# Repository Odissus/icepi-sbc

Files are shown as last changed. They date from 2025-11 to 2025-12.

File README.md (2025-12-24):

# Icepi SBC

A low-cost single-board computer for the H3 CPU: A cheap yet powerful Linux device that you can take anywhere.



| Interested? [Subscribe to updates!](https://cyao.dev/subscribe.html) | Check out [Icepi Zero](https://github.com/cheyao/icepi-zero) too |
| --- | --- |

If there's a lot of people interested, there's a chance that I'll try to sell this at a relatively low price :P

## Features

- H3 Quad-Core ARM Cortex-A7 @ 1.296GHz CPU
    - Mali400 MP2 OpenGL ES 2.0 GPU
- 512MiB of DDR3 RAM, stable at 696MHz (Upgradable to 1GiB)
- Ethernet PHY, WiFi & Bluetooth
- GPDI video out
- USB connectors:
    - 2x USB-A 
    - 2x USB-C (One OTG port)
    - 1x USB-C 100W PD power port
- 3.5mm audio jack
- uSD card slot
- eMMC 5.1 storage



## System support

The single-board computer is capable of running Linux (debian) and Android ([H3Droid](https://h3droid.com/project)). It can output 4k video via it's GPDI-A connector, output a tty consol via UART, or act as an remote host via ssh.

It's small, compact form factor allows it to be a nice portable computer that you can take anywhere! It supports GPU acceleration and 4k video decoding, letting you view anything in full confort.



## PCB

[Check out the online version here](https://github.com/cheyao/icepi-sbc/tree/main/hardware).

The PCB is only 4 layered, ensuring minimal cost and overhead during production. But for mass production 6 layers is recommended, putting solid ground on In.1 and In.4, then copy the power plane to In.2 and In.3. (Impedance matching might be required depending on stackup)



The current setup uses [JLCPCB's](https://jlcpcb.com/) JLC04161H-3313 stackup, and the BOM is optimized for use there. Using other fabs would require re-tuning the DDR3, USB and GPDI traces.

## Open source

This project is licensed under the [Solderpad](/LICENSE) hardware license, granting the maximum amount of liberty :)

It is also OSHWA certified under the identifier [FR000029](https://certification.oshwa.org/fr000029.html).



## Contact

Any questions? Dm `@Cyao.` on Discord (Send a friend request or join the KiCAD Discord server) or send an email to `cyao _at_ duck.com`!

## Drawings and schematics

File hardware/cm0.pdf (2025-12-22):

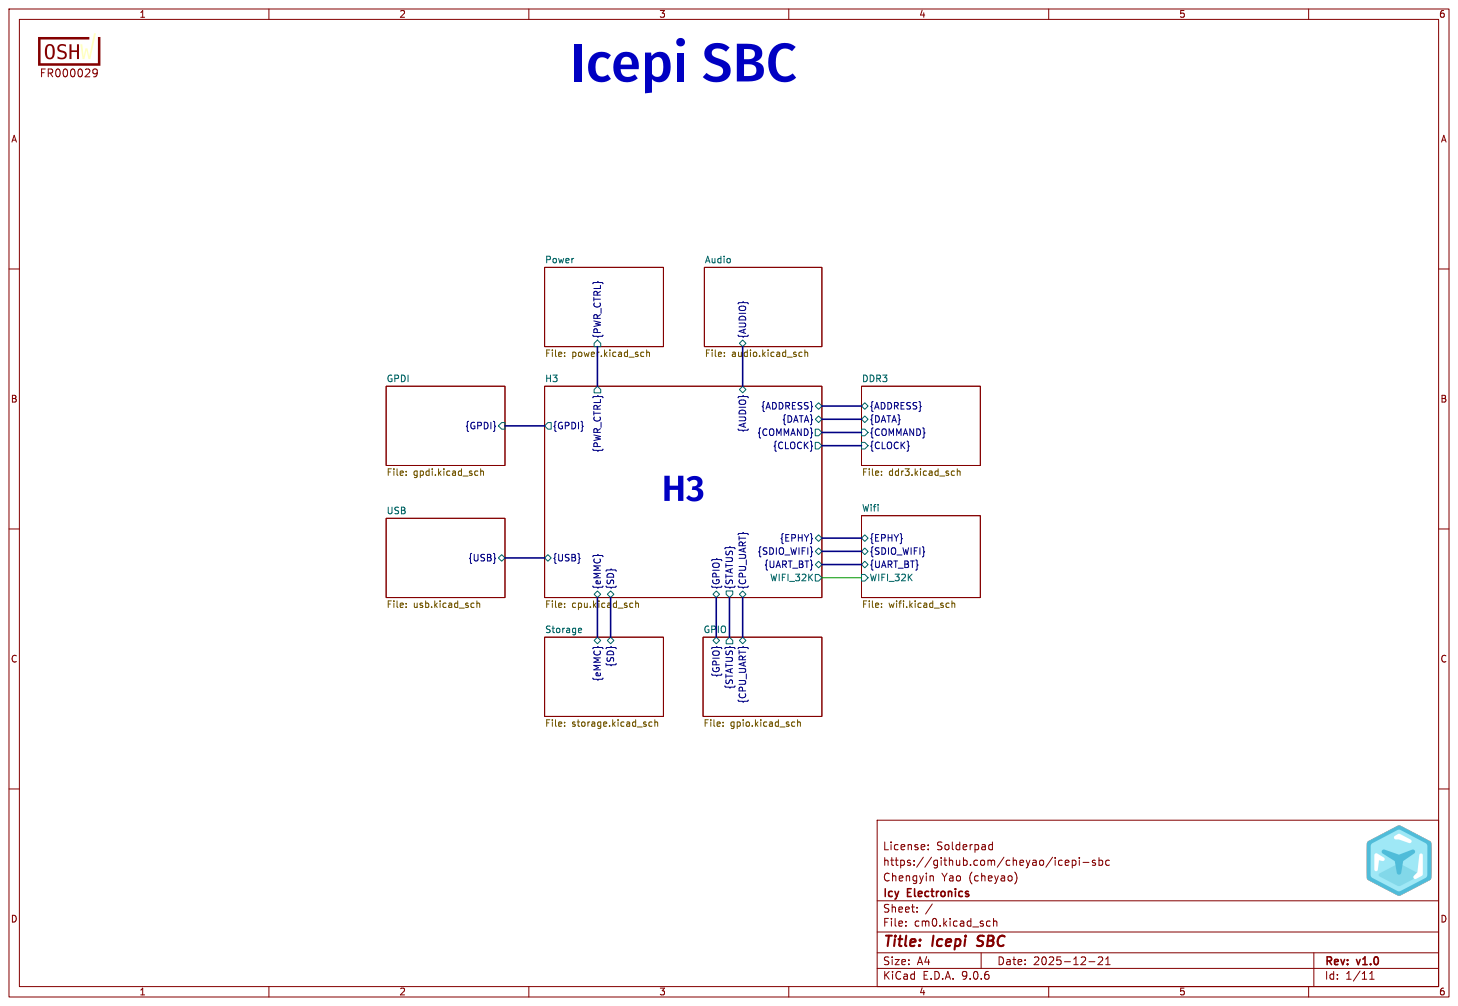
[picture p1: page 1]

File: gpio.kicad_sch {PWR_CTRL} Power File: power.kicad_sch

{EPHY} Wifi File: wifi.kicad_sch {CPU_UART} {STATUS} {GPIO} GPIO

https://github.com/cheyao/icepi-sbc License: Solderpad

File: cm0.kicad_sch Sheet: /
Id: 1/11 Title: Icepi SBC

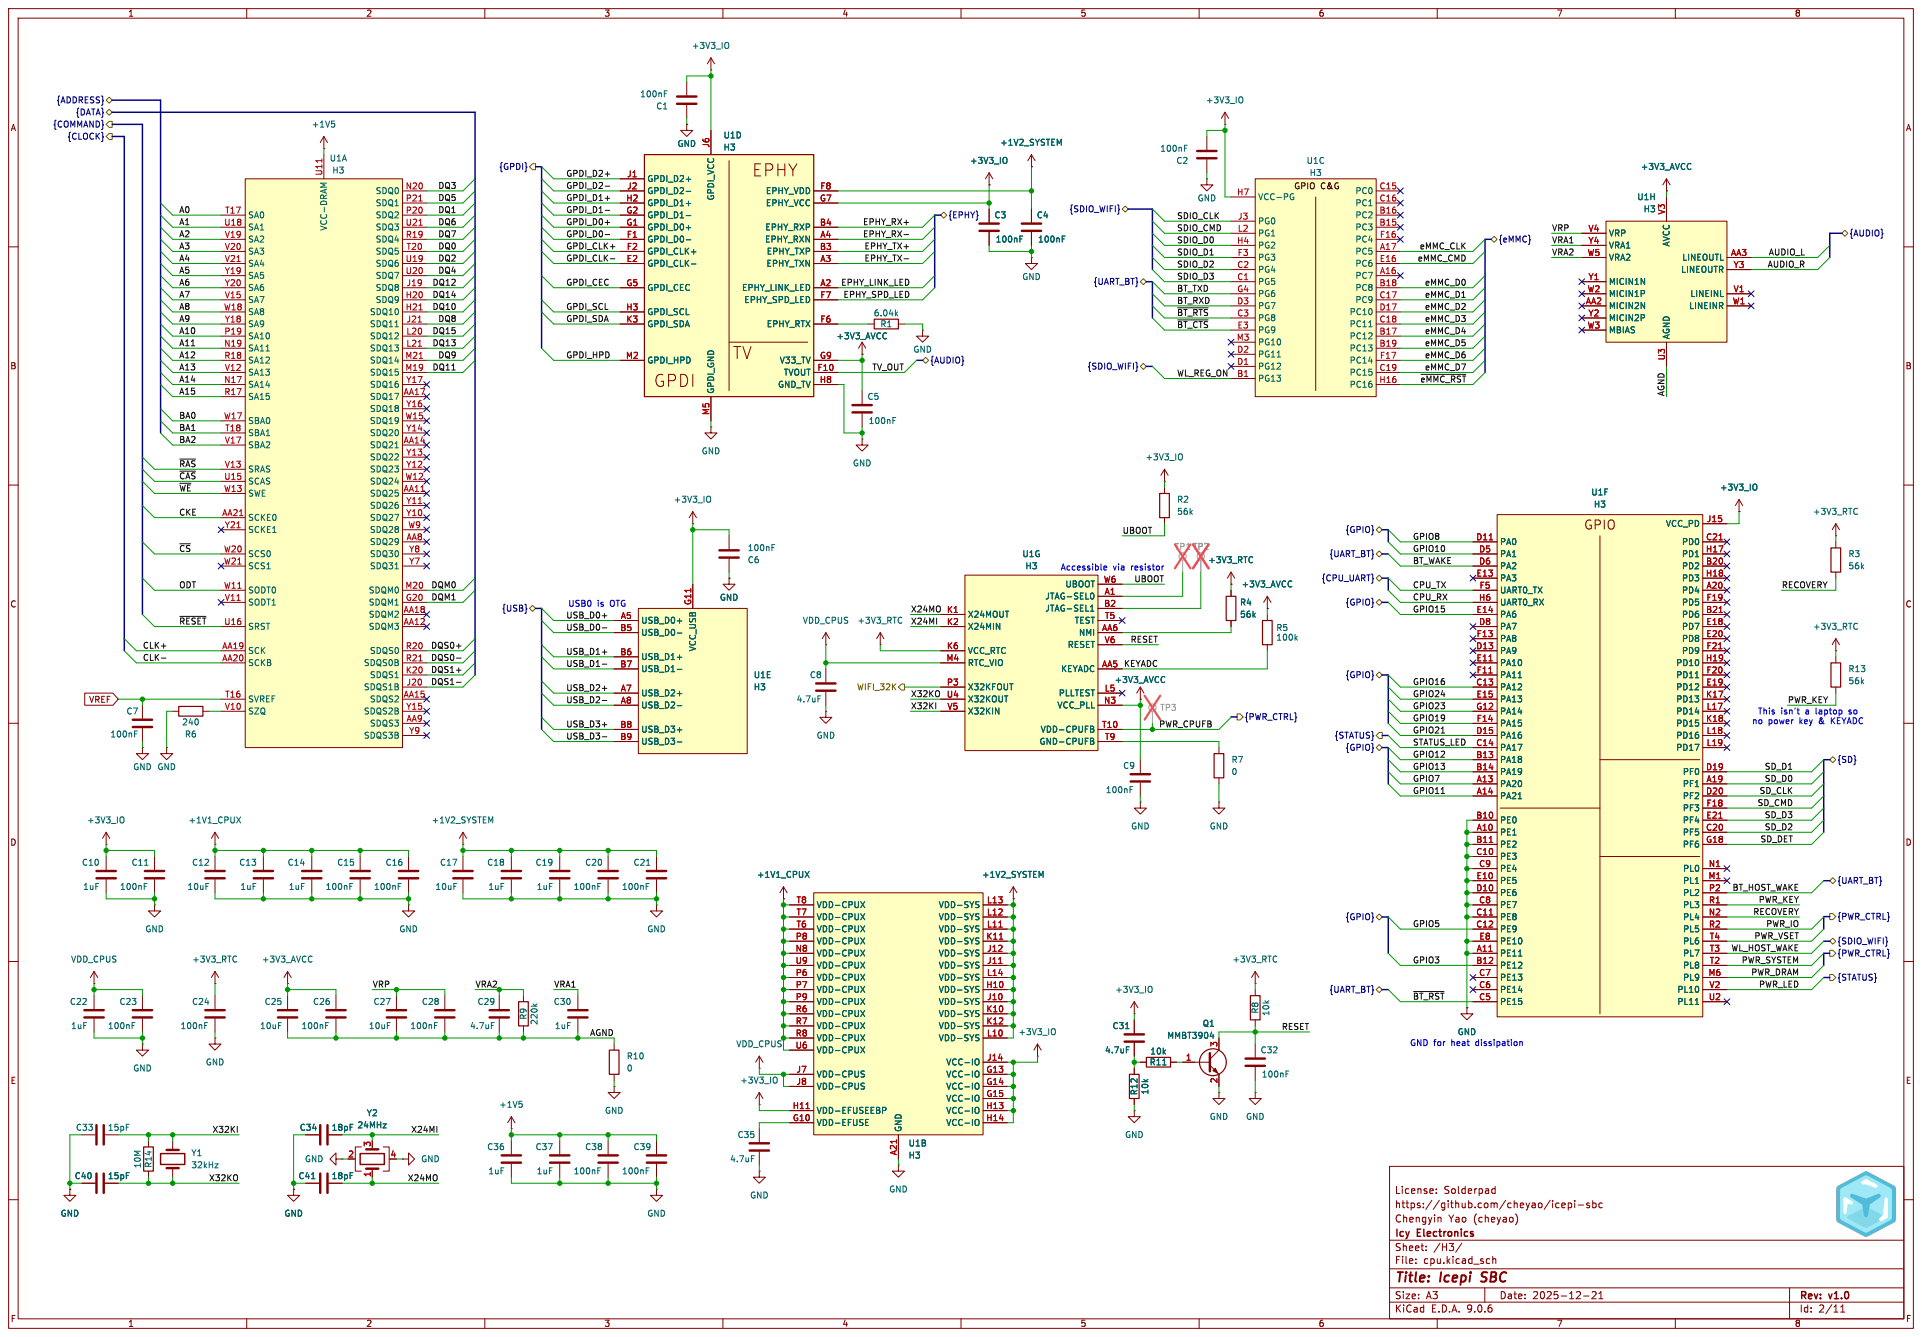
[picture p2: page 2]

3 2 Q1 MMBT3904 +1V2_SYSTEM VCC-DRAM U11 SA0 T17 SA1 U18 SA2 V19 SA3 V20 SA4 V21 SA5 Y19 SA6 Y20 SA7 V15 SA8 W18 SA9 Y18 SA10 P19 SA11 N19 SA12 R18 SA13 V12 SA14 N17 SA15 R17 SBA0 W17 SBA1 T18 SBA2 V17 SRAS V13 SCAS U15 SWE W13 SCKE0 AA21 SCKE1 Y21 SCS0 W20 SCS1 W21 SODT0 W11 SODT1 V11 SRST U16 SCK AA19 SCKB AA20 SVREF T16 SZQ V10

This isn't a laptop so
no power key & KEYADC

https://github.com/cheyao/icepi-sbc License: Solderpad C29

File: cpu.kicad_sch Sheet: /H3/
Id: 2/11 Title: Icepi SBC

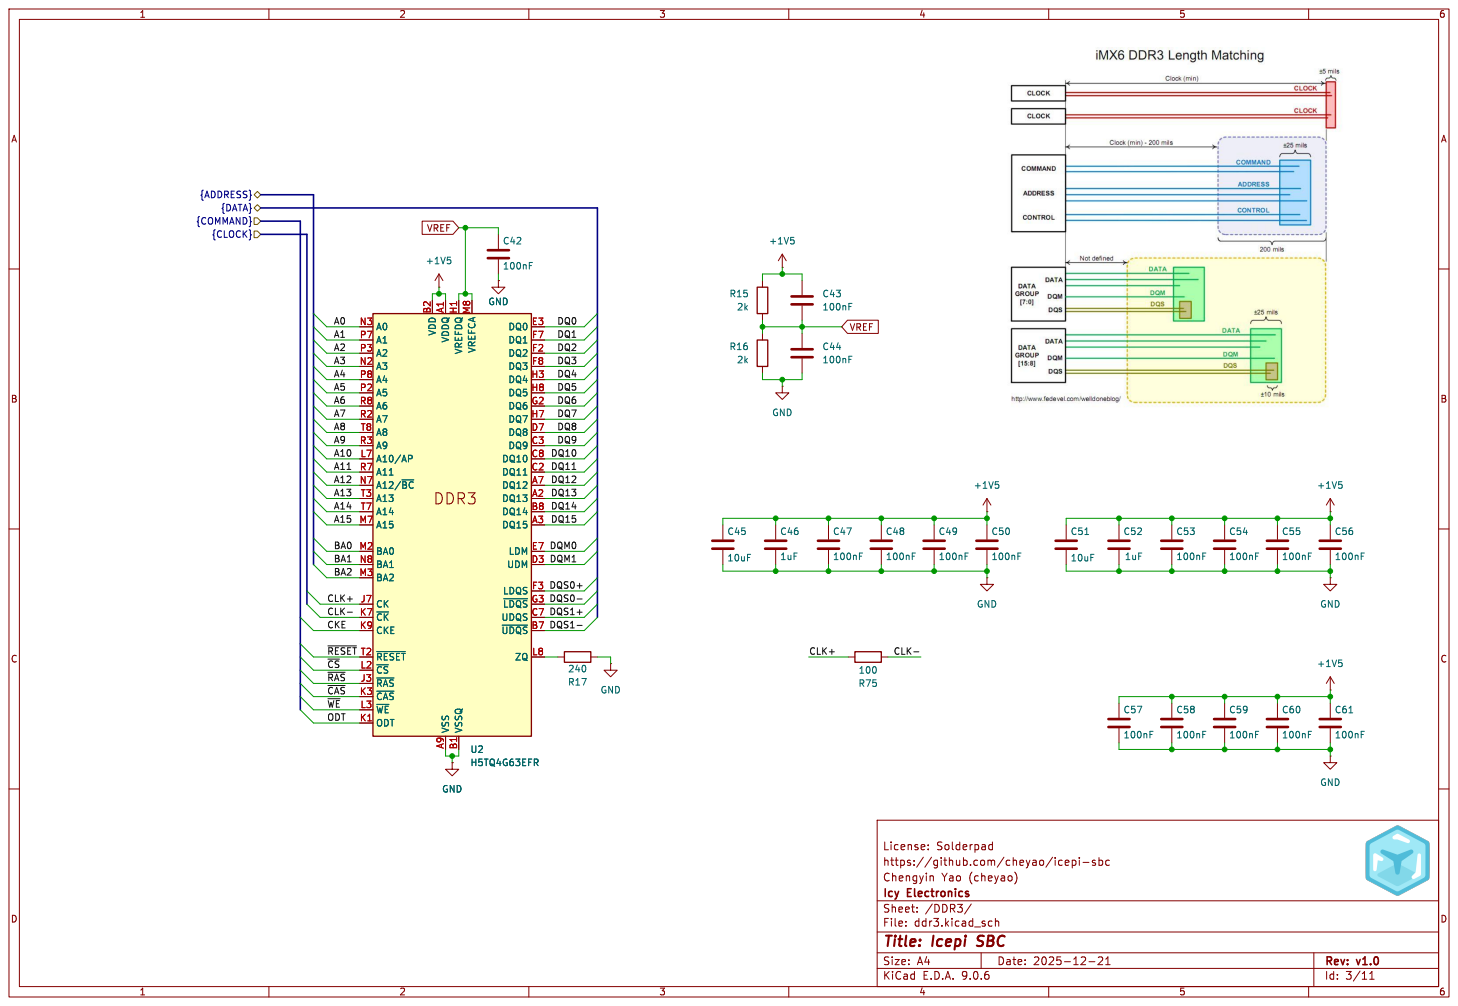
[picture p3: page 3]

https://github.com/cheyao/icepi-sbc License: Solderpad C46

File: ddr3.kicad_sch Sheet: /DDR3/
Id: 3/11 Title: Icepi SBC

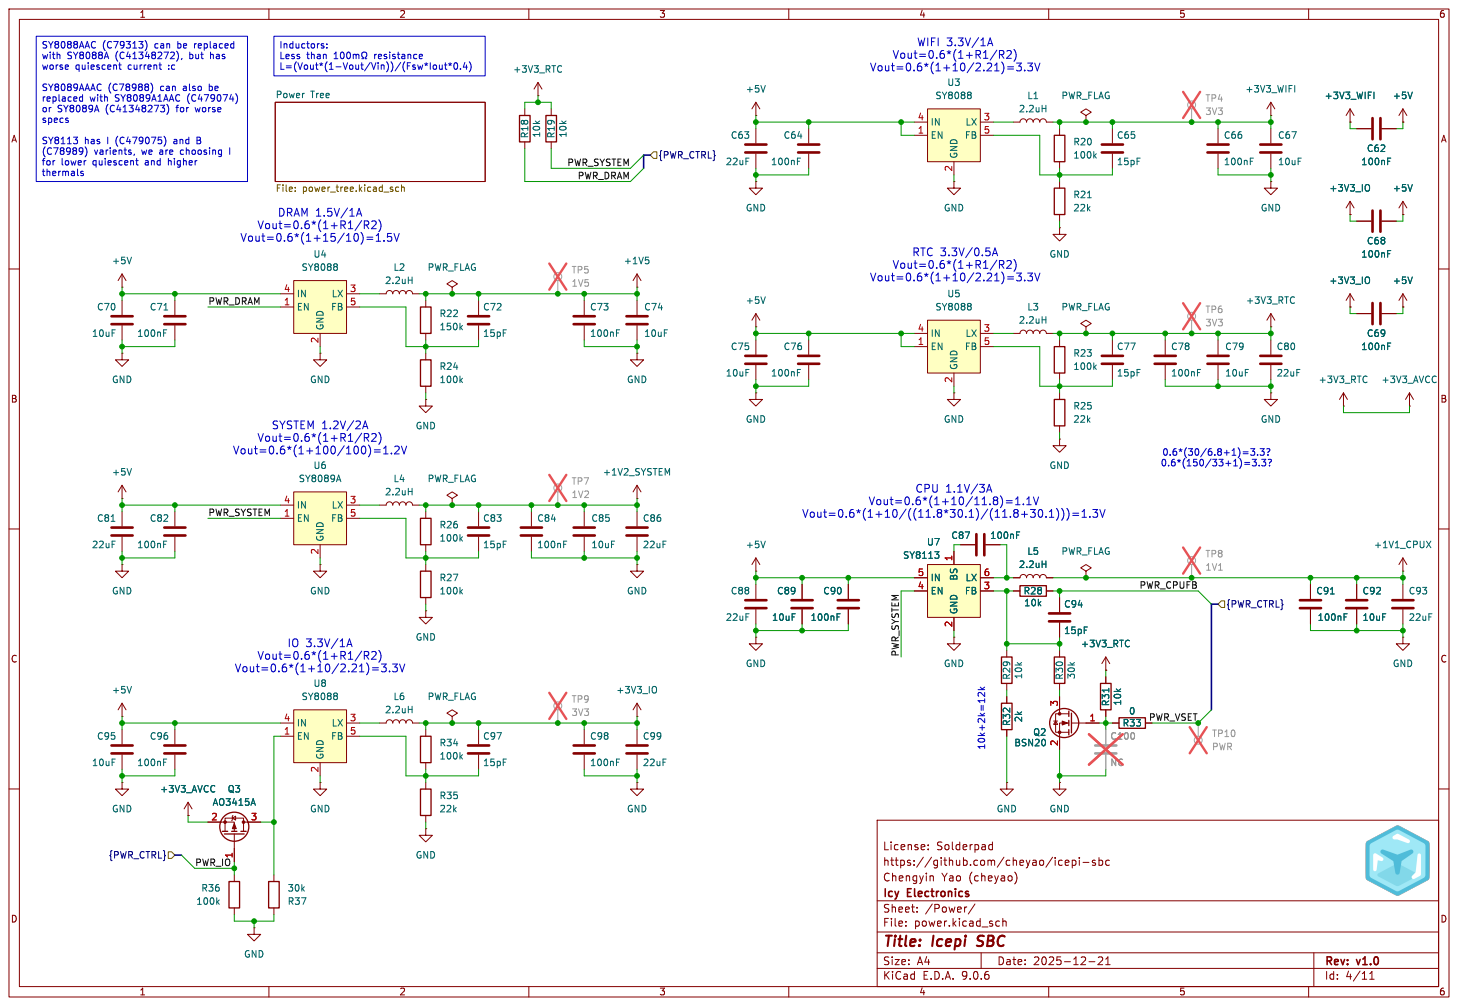
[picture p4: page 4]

Inductors: Less than þÿ100m©resistance

https://github.com/cheyao/icepi-sbc License: Solderpad

File: power.kicad_sch Sheet: /Power/
Id: 4/11 Title: Icepi SBC

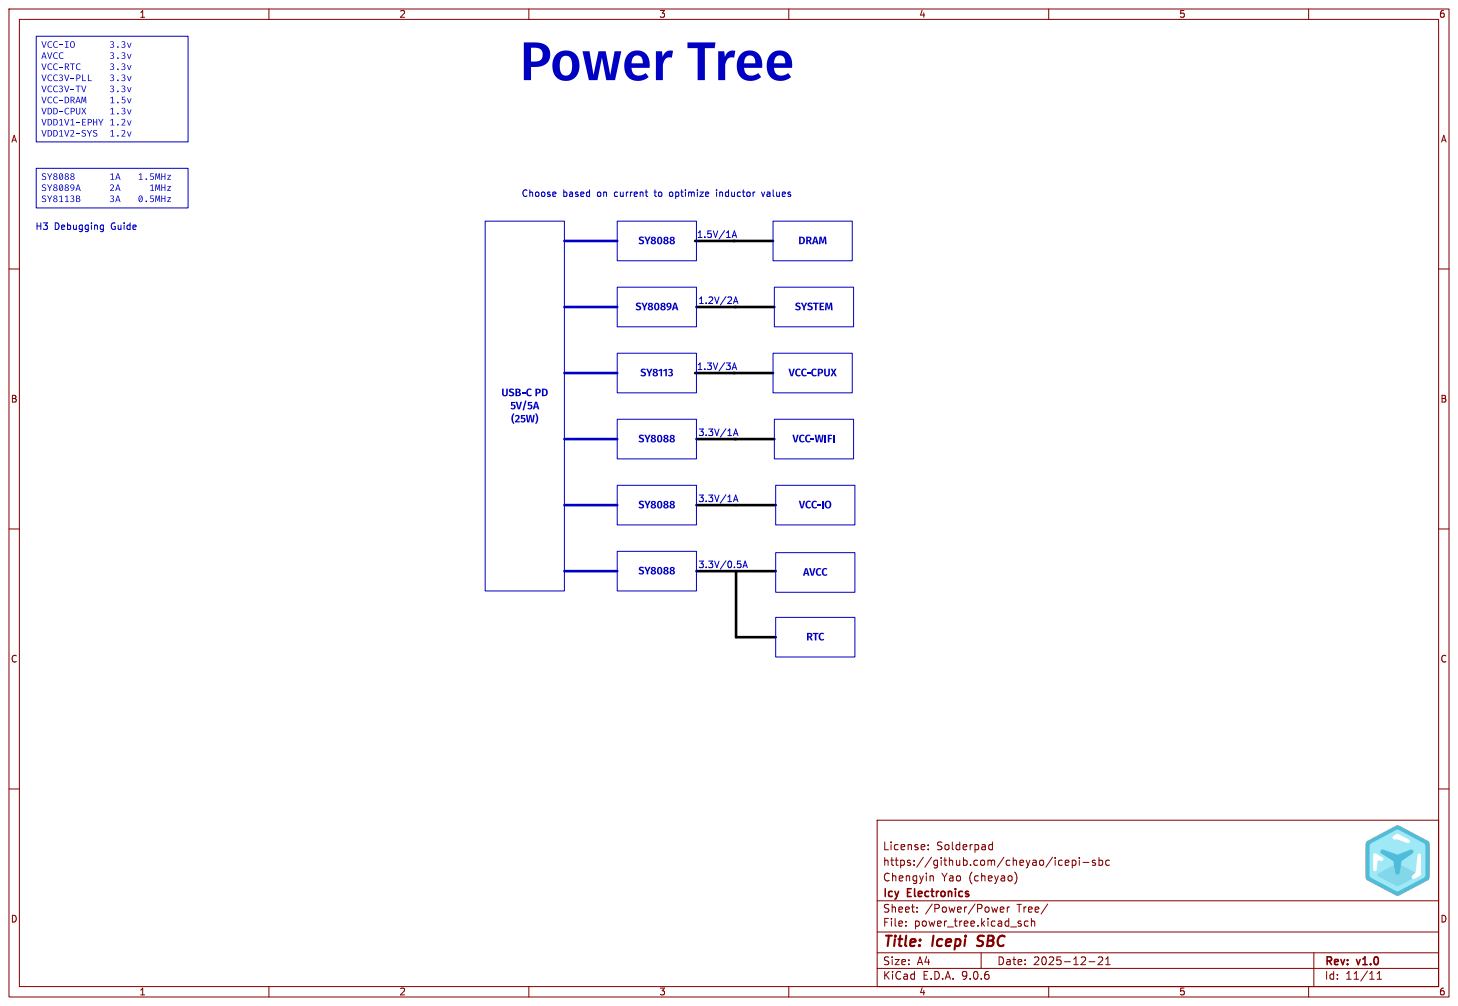
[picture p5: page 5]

https://github.com/cheyao/icepi-sbc License: Solderpad

Id: 11/11 Title: Icepi SBC

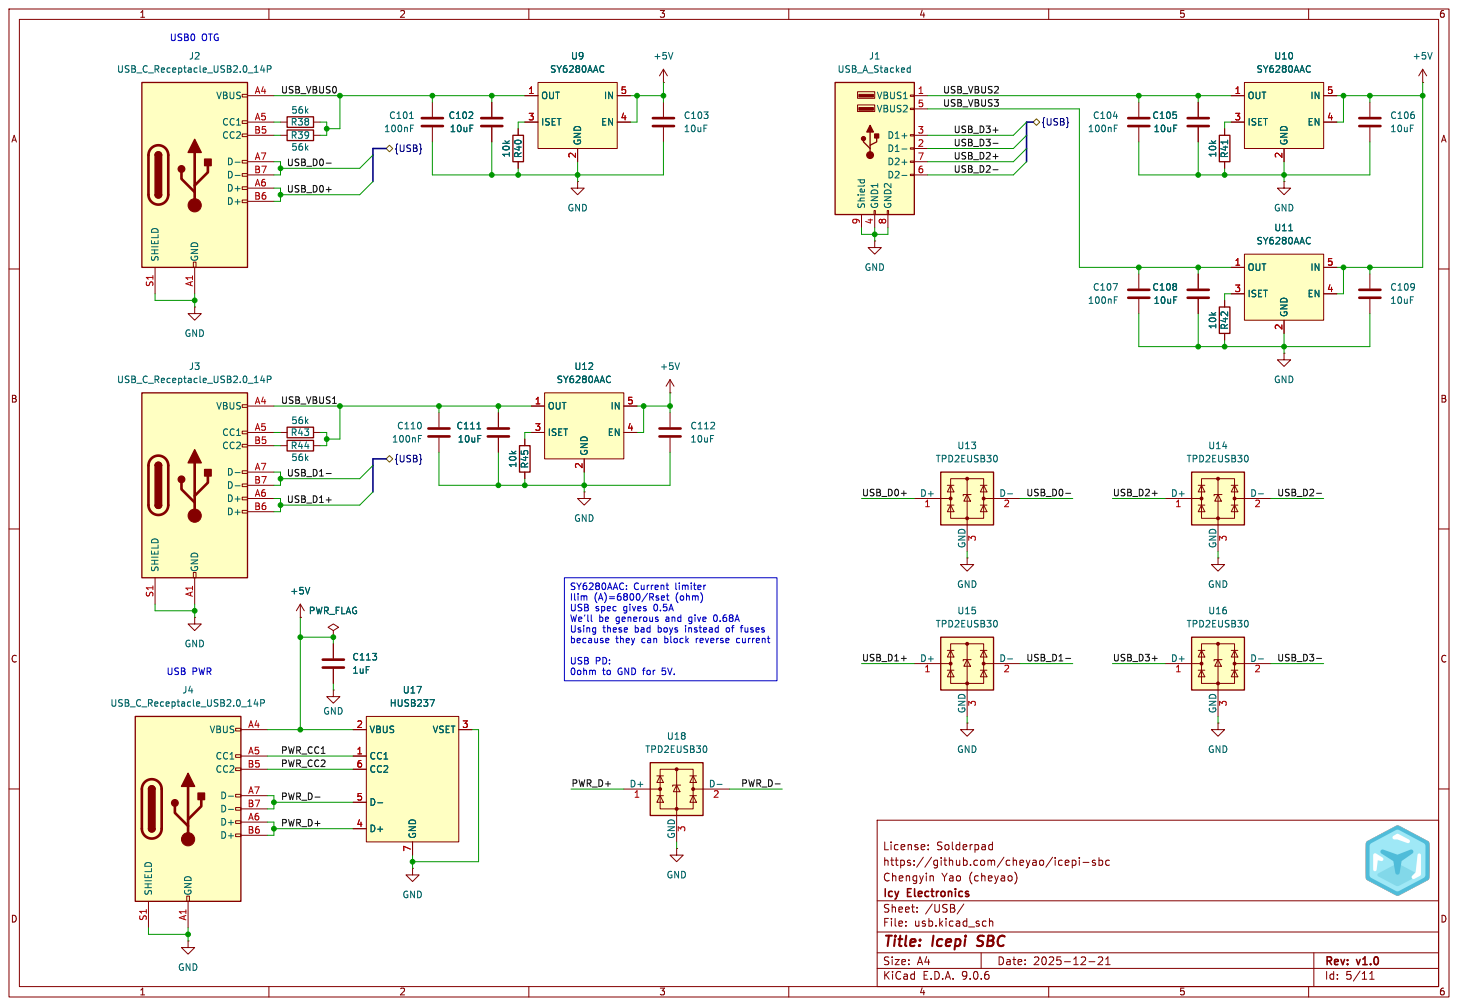
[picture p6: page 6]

https://github.com/cheyao/icepi-sbc License: Solderpad GND

File: usb.kicad_sch Sheet: /USB/
Id: 5/11 Title: Icepi SBC

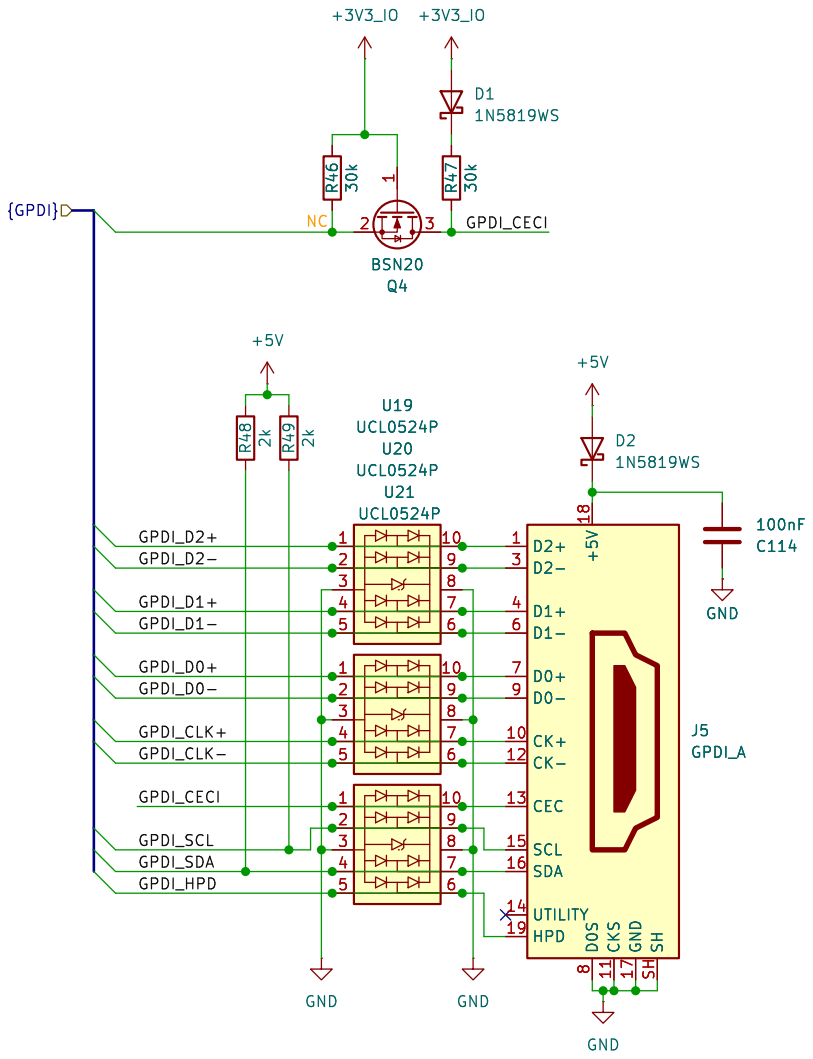
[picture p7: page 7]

https://github.com/cheyao/icepi-sbc License: Solderpad

File: gpdi.kicad_sch Sheet: /GPDI/
Id: 6/11 Title: Icepi SBC

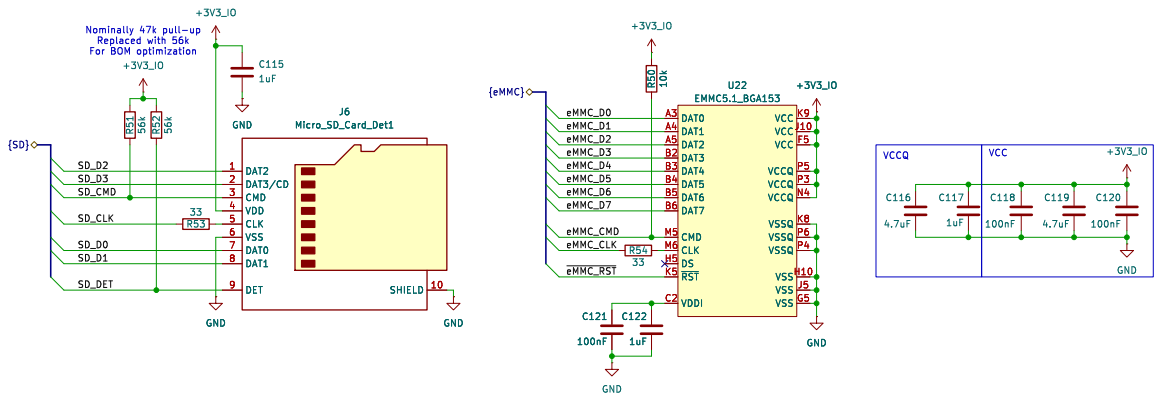
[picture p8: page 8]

https://github.com/cheyao/icepi-sbc License: Solderpad

File: storage.kicad_sch Sheet: /Storage/
Id: 7/11 Title: Icepi SBC

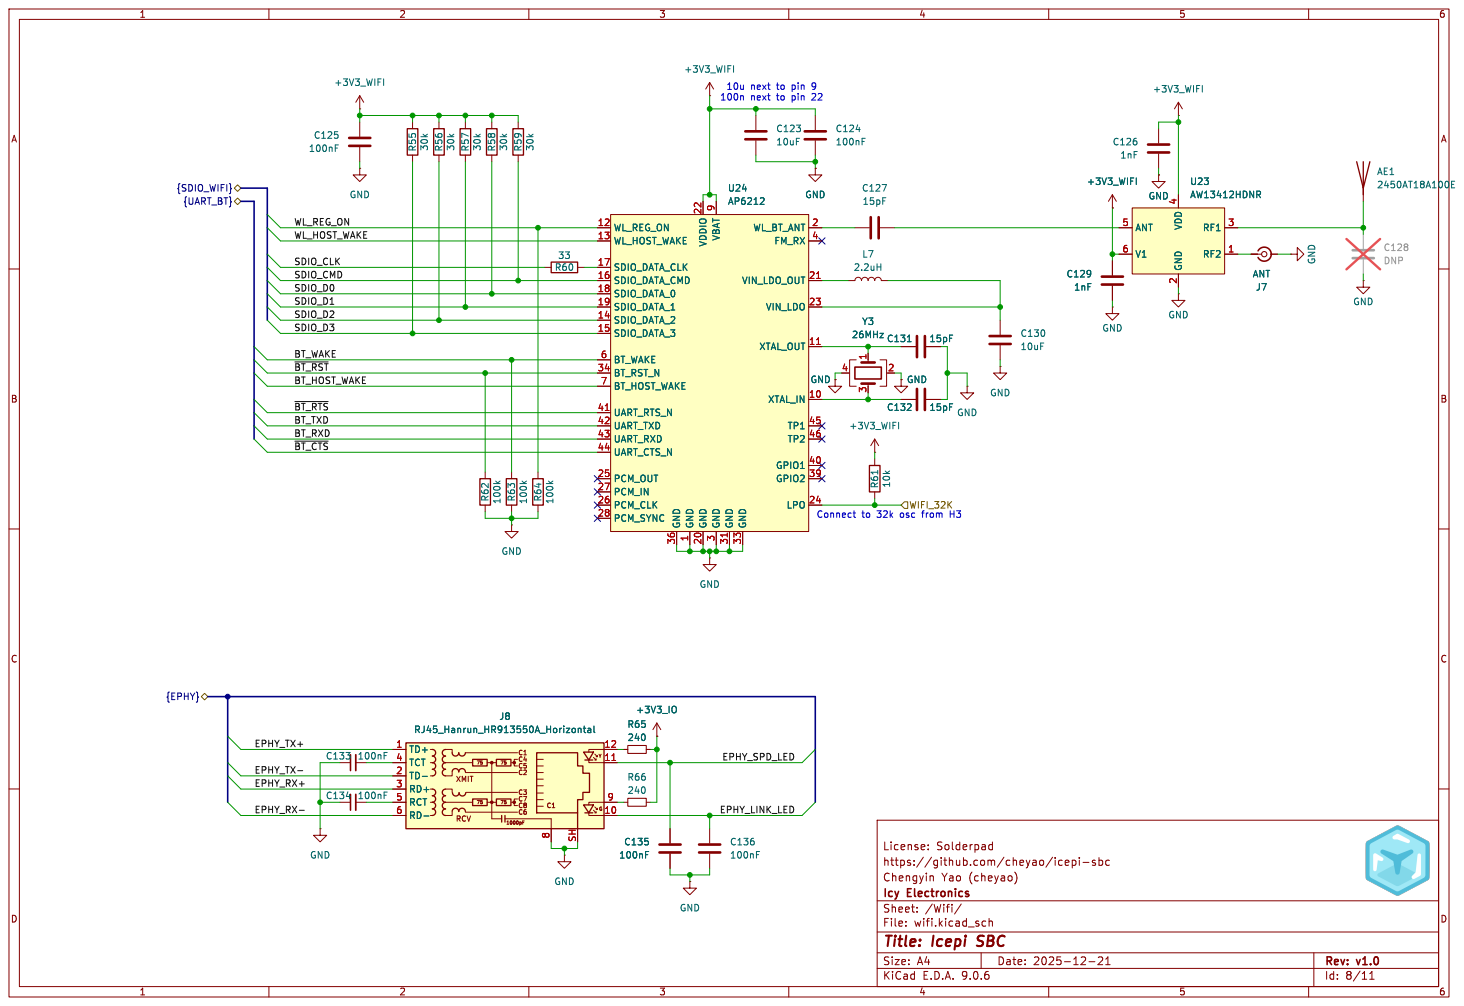
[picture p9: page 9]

10u next to pin 9
100n next to pin 22Connect to 32k osc from H3 GND GND

File: wifi.kicad_sch Sheet: /Wifi/
Id: 8/11 Title: Icepi SBC

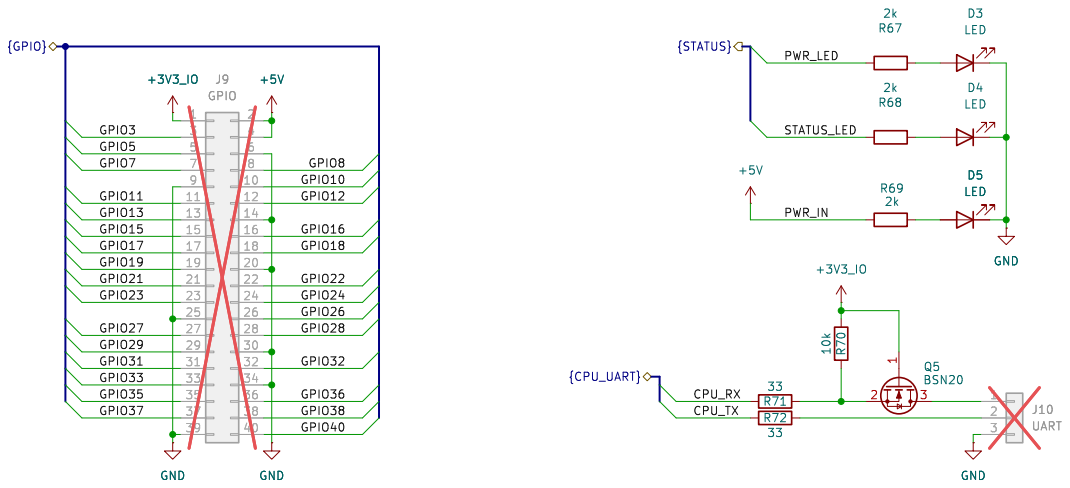
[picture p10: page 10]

File: gpio.kicad_sch Sheet: /GPIO/
Id: 9/11 Title: Icepi SBC

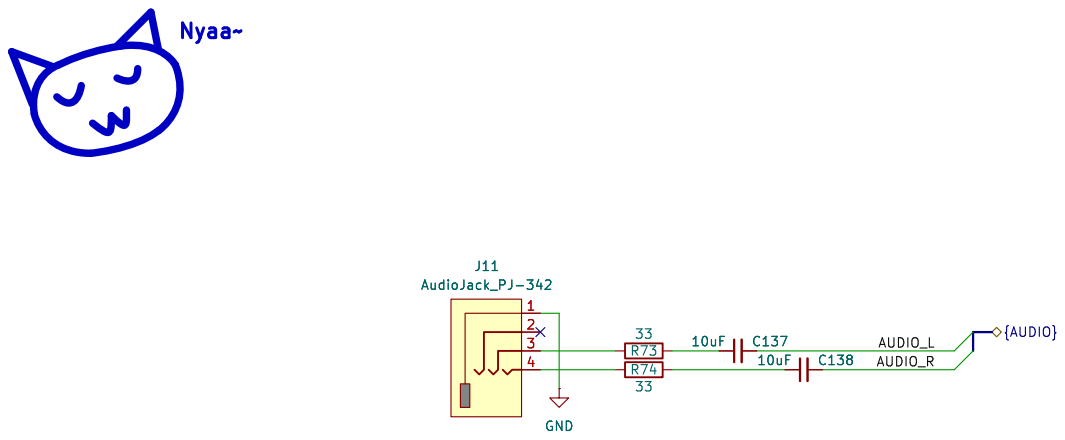
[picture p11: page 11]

https://github.com/cheyao/icepi-sbc License: Solderpad

File: audio.kicad_sch Sheet: /Audio/
Id: 10/11 Title: Icepi SBC

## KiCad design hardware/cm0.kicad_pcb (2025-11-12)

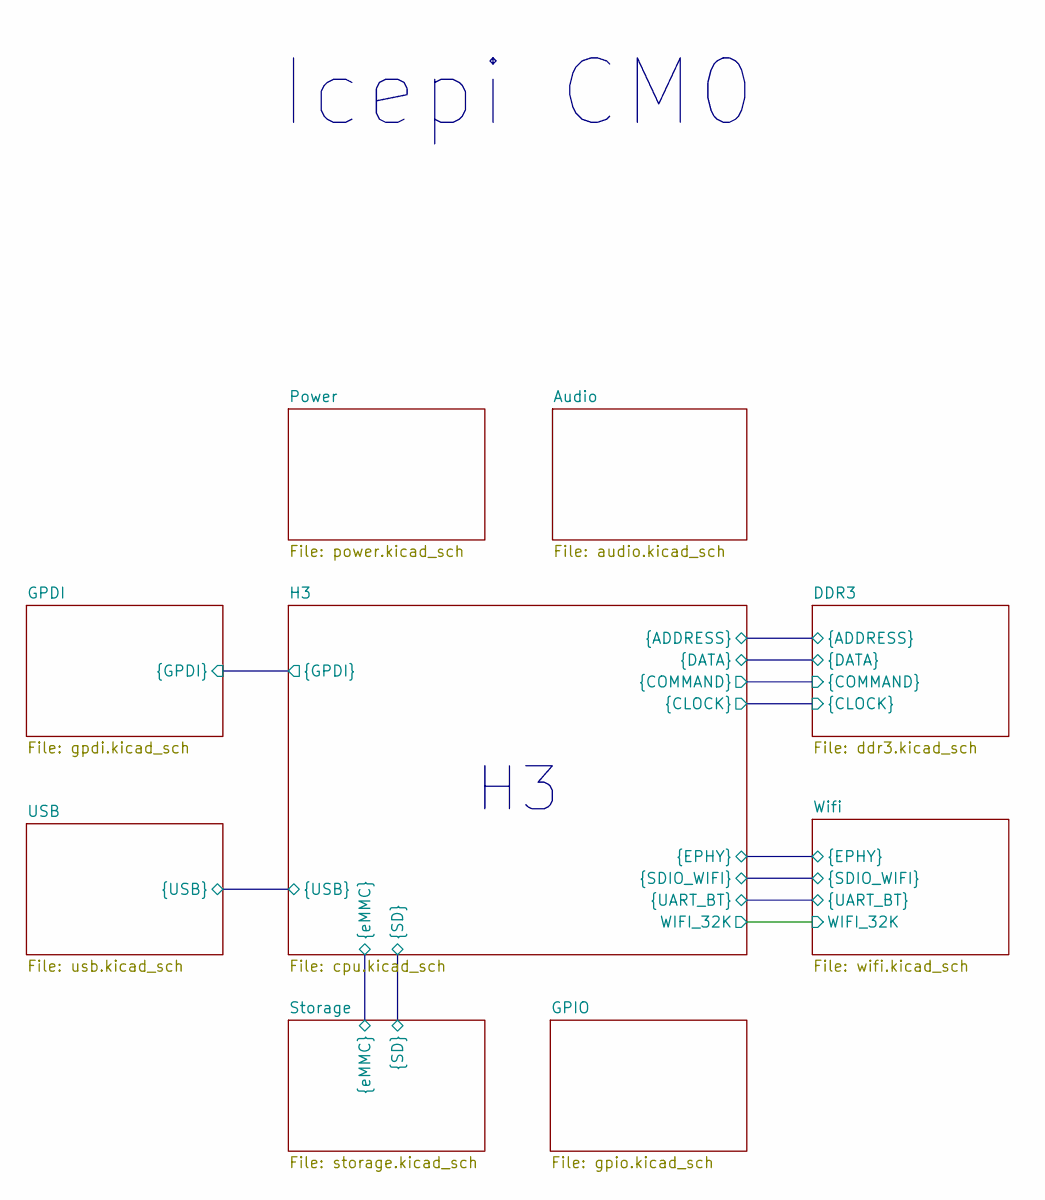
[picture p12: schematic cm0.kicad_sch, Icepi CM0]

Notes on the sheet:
Icepi CM0

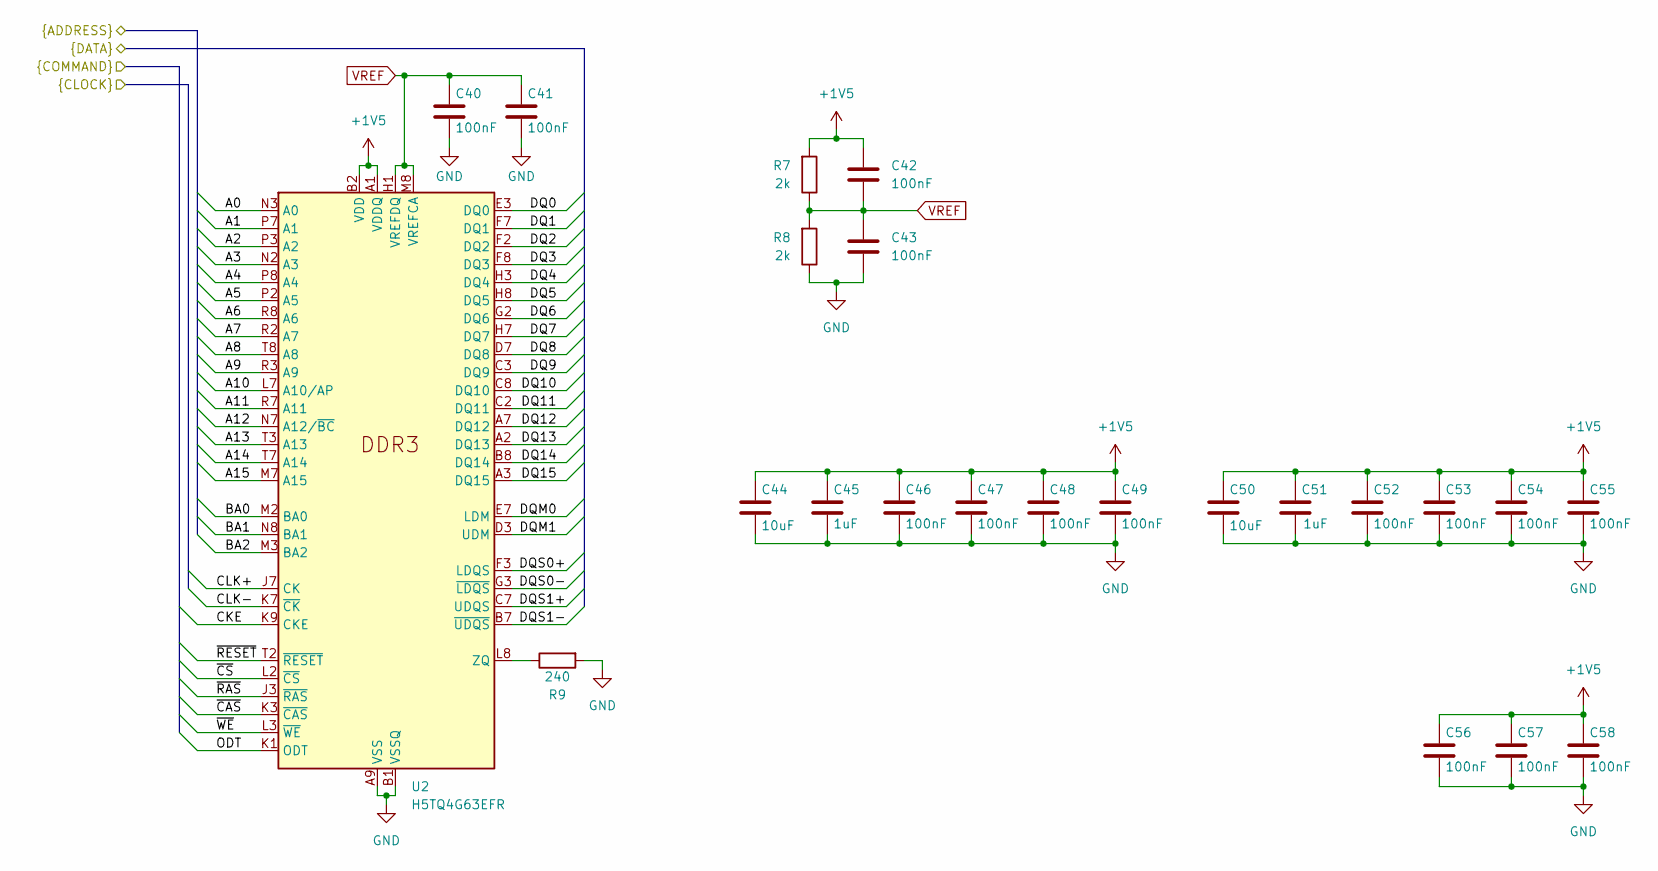
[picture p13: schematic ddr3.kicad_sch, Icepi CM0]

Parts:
C40, C41, C42, C43, C46, C47, C48, C49, C52, C53, C54, C55, C56, C57, C58: 100nF; C_0402_1005Metric; LCSC Part # C1525
C44, C50: 10uF; C_0603_1608Metric; LCSC Part # C19702
C45, C51: 1uF; C_0402_1005Metric; LCSC Part # C52923
R7, R8: 2k; R_0402_1005Metric; LCSC Part # C4109
R9: 240; R_0603_1608Metric; LCSC Part # C23350
U2: H5TQ4G63EFR; FBGA-96_7.5x13mm_Layout9x16_P0.8mm; LCSC Part # C2803259

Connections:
+1V5: C42.1, C44.1, C45.2, C46.1, C47.1, C48.1, C49.1, C50.1, C51.2, C52.1, C53.1, C54.1, C55.1, C56.1, C57.1, C58.1, R7.2, U2.A1 (VDDQ), U2.A8 (VDDQ), U2.B2 (VDD), U2.C1 (VDDQ), U2.C9 (VDDQ), U2.D2 (VDDQ), U2.D9 (VDD), U2.E9 (VDDQ), U2.F1 (VDDQ), U2.G7 (VDD), U2.H2 (VDDQ), U2.H9 (VDDQ), U2.K2 (VDD), U2.K8 (VDD), U2.N1 (VDD), U2.N9 (VDD), U2.R1 (VDD), U2.R9 (VDD); also elsewhere on the board
/DDR3/A0: U2.N3 (A0); also elsewhere on the board
/DDR3/A1: U2.P7 (A1); also elsewhere on the board
/DDR3/A2: U2.P3 (A2); also elsewhere on the board
/DDR3/A3: U2.N2 (A3); also elsewhere on the board
/DDR3/A4: U2.P8 (A4); also elsewhere on the board
/DDR3/A5: U2.P2 (A5); also elsewhere on the board
/DDR3/A6: U2.R8 (A6); also elsewhere on the board
/DDR3/A7: U2.R2 (A7); also elsewhere on the board
/DDR3/A8: U2.T8 (A8); also elsewhere on the board
/DDR3/A9: U2.R3 (A9); also elsewhere on the board
/DDR3/A10: U2.L7 (A10/AP); also elsewhere on the board
/DDR3/A11: U2.R7 (A11); also elsewhere on the board
/DDR3/A12: U2.N7 (A12/~BC); also elsewhere on the board
/DDR3/A13: U2.T3 (A13); also elsewhere on the board
/DDR3/A14: U2.T7 (A14); also elsewhere on the board
/DDR3/A15: U2.M7 (A15); also elsewhere on the board
/DDR3/BA0: U2.M2 (BA0); also elsewhere on the board
/DDR3/BA1: U2.N8 (BA1); also elsewhere on the board
/DDR3/BA2: U2.M3 (BA2); also elsewhere on the board
/DDR3/CKE: U2.K9 (CKE); also elsewhere on the board
/DDR3/CLK+: U2.J7 (CK); also elsewhere on the board
/DDR3/CLK-: U2.K7 (~CK); also elsewhere on the board
/DDR3/DQ0: U2.E3 (DQ0); also elsewhere on the board
/DDR3/DQ1: U2.F7 (DQ1); also elsewhere on the board
/DDR3/DQ2: U2.F2 (DQ2); also elsewhere on the board
/DDR3/DQ3: U2.F8 (DQ3); also elsewhere on the board
/DDR3/DQ4: U2.H3 (DQ4); also elsewhere on the board
/DDR3/DQ5: U2.H8 (DQ5); also elsewhere on the board
/DDR3/DQ6: U2.G2 (DQ6); also elsewhere on the board
/DDR3/DQ7: U2.H7 (DQ7); also elsewhere on the board
/DDR3/DQ8: U2.D7 (DQ8); also elsewhere on the board
/DDR3/DQ9: U2.C3 (DQ9); also elsewhere on the board
/DDR3/DQ10: U2.C8 (DQ10); also elsewhere on the board
/DDR3/DQ11: U2.C2 (DQ11); also elsewhere on the board
/DDR3/DQ12: U2.A7 (DQ12); also elsewhere on the board
/DDR3/DQ13: U2.A2 (DQ13); also elsewhere on the board
/DDR3/DQ14: U2.B8 (DQ14); also elsewhere on the board
/DDR3/DQ15: U2.A3 (DQ15); also elsewhere on the board
/DDR3/DQM0: U2.E7 (LDM); also elsewhere on the board
/DDR3/DQM1: U2.D3 (UDM); also elsewhere on the board
/DDR3/DQS0+: U2.F3 (LDQS); also elsewhere on the board
/DDR3/DQS0-: U2.G3 (~LDQS); also elsewhere on the board
/DDR3/DQS1+: U2.C7 (UDQS); also elsewhere on the board
/DDR3/DQS1-: U2.B7 (~UDQS); also elsewhere on the board
/DDR3/ODT: U2.K1 (ODT); also elsewhere on the board
/DDR3/~CAS: U2.K3 (~CAS); also elsewhere on the board
/DDR3/~CS: U2.L2 (~CS); also elsewhere on the board
/DDR3/~RAS: U2.J3 (~RAS); also elsewhere on the board
/DDR3/~RESET: U2.T2 (~RESET); also elsewhere on the board
/DDR3/~WE: U2.L3 (~WE); also elsewhere on the board
GND: C40.2, C41.2, C43.2, C44.2, C45.1, C46.2, C47.2, C48.2, C49.2, C50.2, C51.1, C52.2, C53.2, C54.2, C55.2, C56.2, C57.2, C58.2, R8.1, R9.2, U2.A9 (VSS), U2.B1 (VSSQ), U2.B3 (VSS), U2.B9 (VSSQ), U2.D1 (VSSQ), U2.D8 (VSSQ), U2.E1 (VSS), U2.E2 (VSSQ), U2.E8 (VSSQ), U2.F9 (VSSQ), U2.G1 (VSSQ), U2.G8 (VSS), U2.G9 (VSSQ), U2.J2 (VSS), U2.J8 (VSS), U2.M1 (VSS), U2.M9 (VSS), U2.P1 (VSS), U2.P9 (VSS), U2.T1 (VSS), U2.T9 (VSS); also elsewhere on the board
unnamed: R9.1, U2.L8 (ZQ)
VREF: C40.1, C41.1, C42.2, C43.1, R7.1, R8.2, U2.H1 (VREFDQ), U2.M8 (VREFCA); also elsewhere on the board

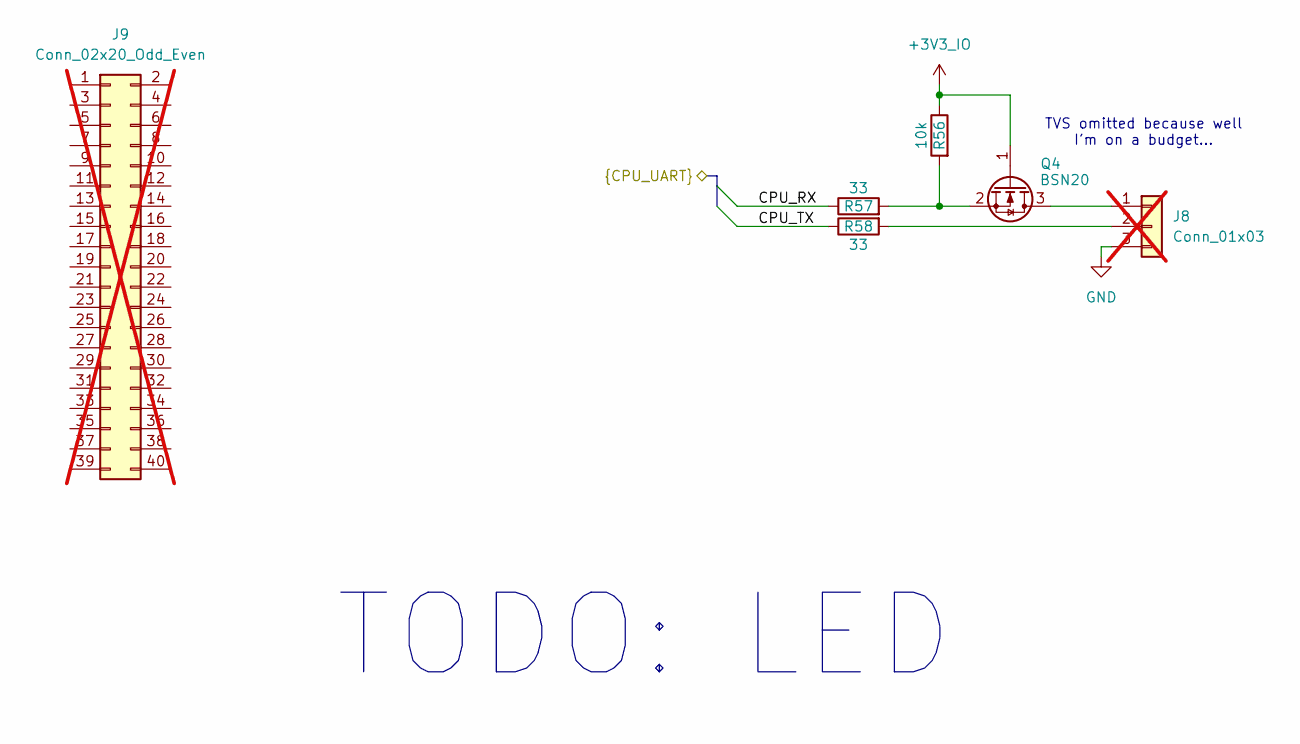
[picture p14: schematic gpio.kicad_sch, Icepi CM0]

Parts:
J8: Conn_01x03; PinHeader_1x03_P2.54mm_Vertical; not fitted
J9: Conn_02x20_Odd_Even; PinHeader_2x20_P2.54mm_Vertical; not fitted
Q4: BSN20; SOT-23; LCSC Part # C116157
R56: 10k; R_0402_1005Metric; LCSC Part # C25744
R57, R58: 33; R_0402_1005Metric; LCSC Part # C25105

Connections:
+3V3_IO: Q4.1 (G), R56.1; also elsewhere on the board
/GPIO/CPU_RX: R57.1; also elsewhere on the board
/GPIO/CPU_TX: R58.1; also elsewhere on the board
GND: J8.3; also elsewhere on the board
unnamed: J8.1, Q4.3 (D)
unnamed: J8.2, R58.2
unnamed: Q4.2 (S), R56.2, R57.2

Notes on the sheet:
TODO: LED
TVS omitted because well I'm on a budget...

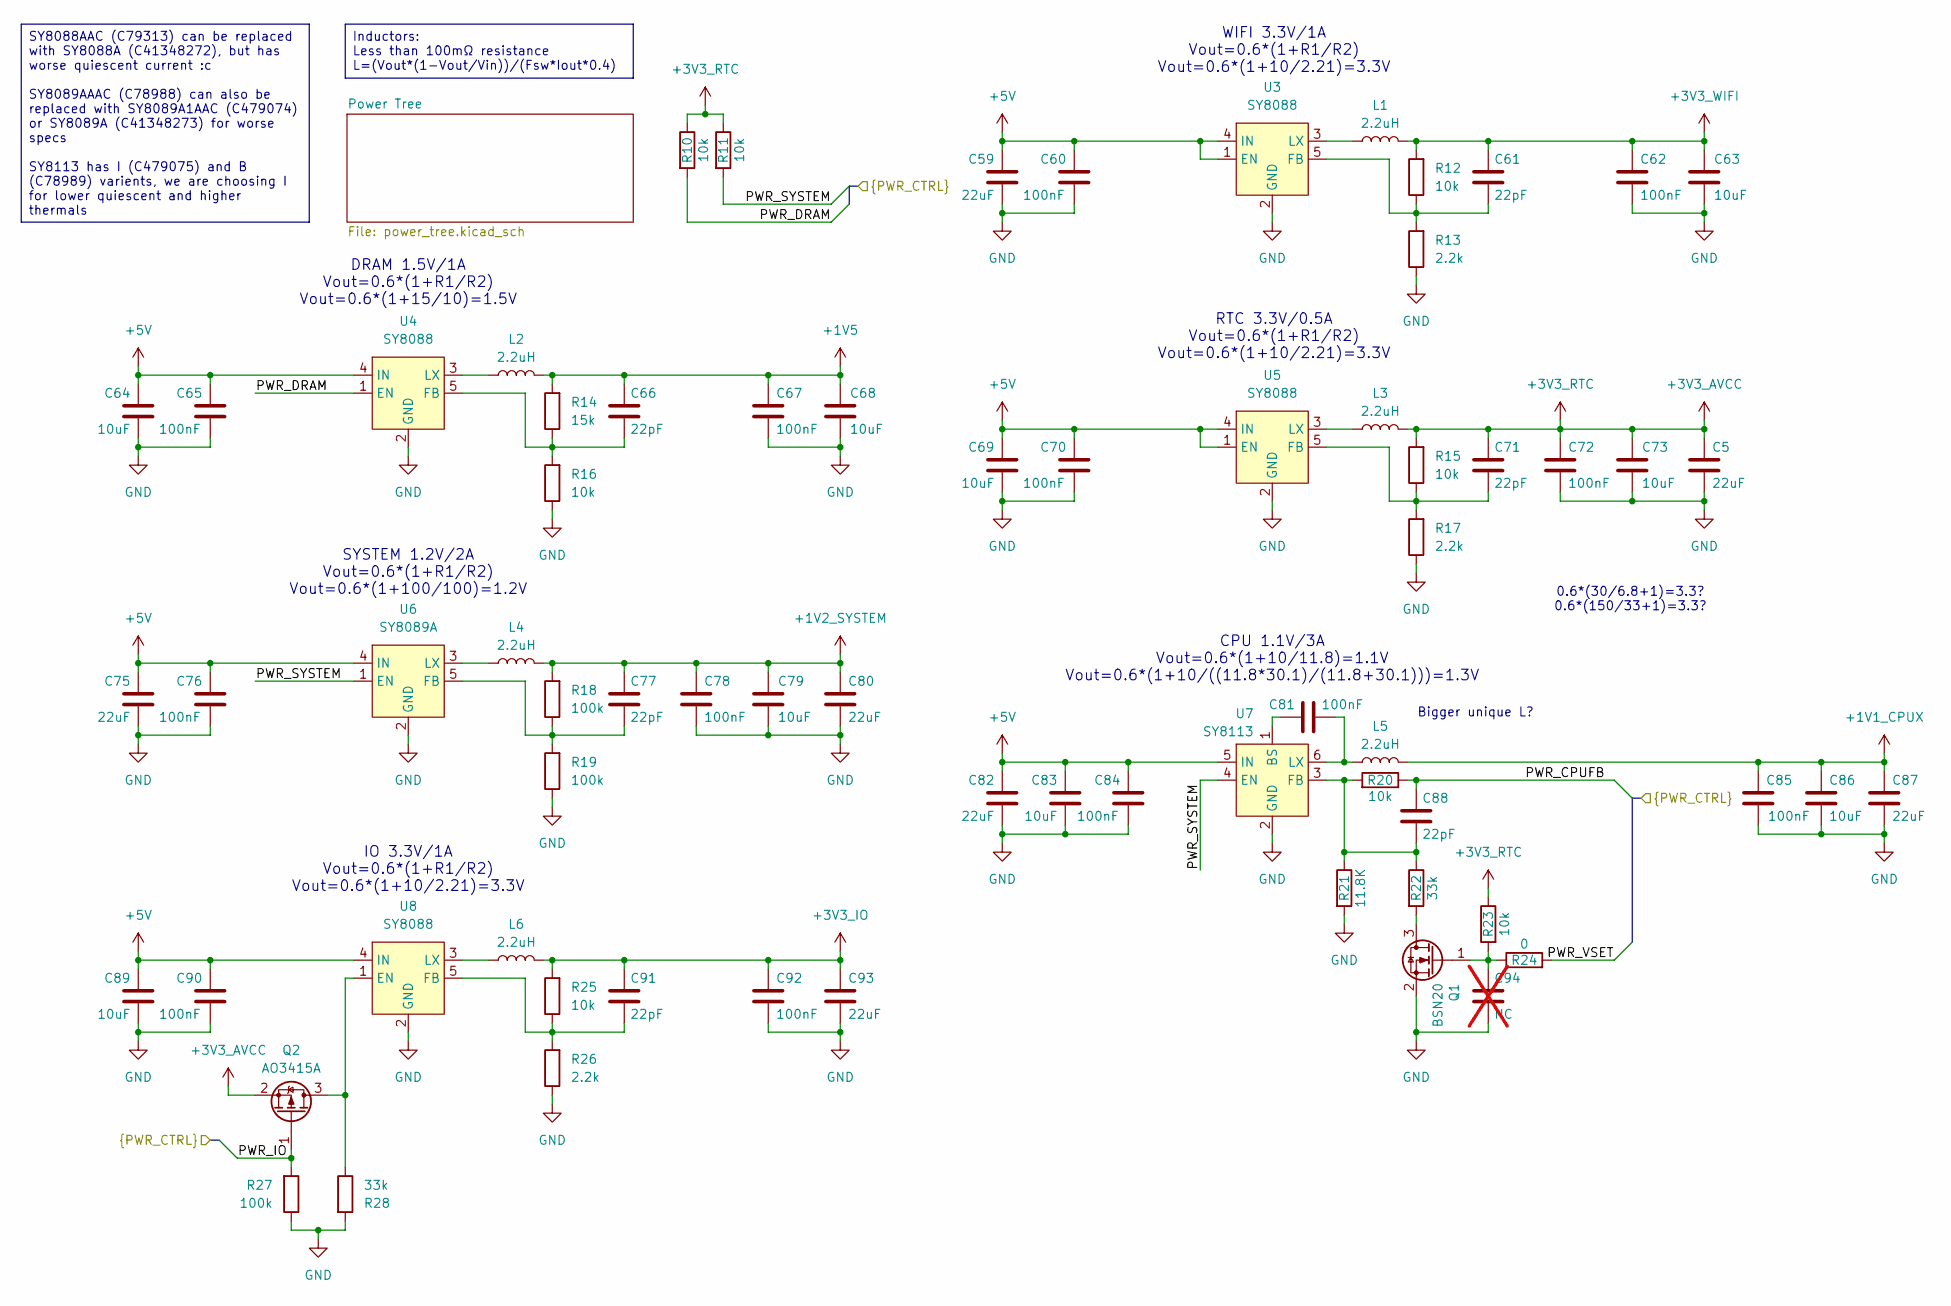
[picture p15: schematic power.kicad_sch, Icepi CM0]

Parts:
C5, C59, C75, C80, C82, C87, C93: 22uF; C_0603_1608Metric; LCSC Part # C59461
C60, C62, C65, C67, C70, C72, C76, C78, C81, C84, C85, C90, C92: 100nF; C_0402_1005Metric; LCSC Part # C1525
C61, C66, C71, C77, C88, C91: 22pF; C_0402_1005Metric; LCSC Part # C1555
C63, C64, C68, C69, C73, C79, C83, C86, C89: 10uF; C_0603_1608Metric; LCSC Part # C19702
C94: NC; C_0402_1005Metric; not fitted
L1, L2, L3, L6: 2.2uH; L_Sunlord_SWPA3015S; LCSC Part # C19734
L4, L5: 2.2uH; L_Sunlord_SWPA4030S; LCSC Part # C135262
Q1: BSN20; SOT-23; LCSC Part # C116157
Q2: AO3415A; SOT-23; LCSC Part # C347479
R10, R11, R12, R15, R16, R20, R23, R25: 10k; R_0402_1005Metric; LCSC Part # C25744
R13, R17, R26: 2.2k; R_0402_1005Metric; LCSC Part # C25879
R14: 15k; R_0402_1005Metric; LCSC Part # C25756
R18, R19, R27: 100k; R_0402_1005Metric; LCSC Part # C25741
R21: 11.8K; R_0402_1005Metric; LCSC Part # C2929934
R22, R28: 33k; R_0402_1005Metric; LCSC Part # C25779
R24: 0; R_0402_1005Metric; LCSC Part # C17168
U3, U4, U5, U8: SY8088; SOT-23-5; LCSC Part # C79313
U6: SY8089A; SOT-23-5; LCSC Part # C78988
U7: SY8113; TSOT-23-6; LCSC Part # C479075

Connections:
+1V1_CPUX: C85.2, C86.1, C87.1, L5.2; also elsewhere on the board
+1V2_SYSTEM: C77.1, C78.2, C79.1, C80.1, L4.2, R18.2; also elsewhere on the board
+1V5: C66.1, C67.2, C68.1, L2.2, R14.2; also elsewhere on the board
+3V3_AVCC: C5.1, C71.1, C72.2, C73.1, L3.2, Q2.2 (S), R10.1, R11.1, R15.2, R23.1; also elsewhere on the board
+3V3_IO: C91.1, C92.2, C93.1, L6.2, R25.2; also elsewhere on the board
+3V3_WIFI: C61.1, C62.2, C63.1, L1.2, R12.2; also elsewhere on the board
+5V: C59.1, C60.2, C64.1, C65.2, C69.1, C70.2, C75.1, C76.2, C82.1, C83.1, C84.2, C89.1, C90.2, U3.1 (EN), U3.4 (IN), U4.4 (IN), U5.1 (EN), U5.4 (IN), U6.4 (IN), U7.5 (IN), U8.4 (IN); also elsewhere on the board
/H3/PWR_CPUFB: C88.1, R20.1; also elsewhere on the board
/H3/PWR_DRAM: R10.2, U4.1 (EN); also elsewhere on the board
/H3/PWR_IO: Q2.1 (G), R27.2; also elsewhere on the board
/H3/PWR_SYSTEM: R11.2, U6.1 (EN), U7.4 (EN); also elsewhere on the board
/H3/PWR_VSET: R24.2; also elsewhere on the board
GND: C5.2, C59.2, C60.1, C62.1, C63.2, C64.2, C65.1, C67.1, C68.2, C69.2, C70.1, C72.1, C73.2, C75.2, C76.1, C78.1, C79.2, C80.2, C82.2, C83.2, C84.1, C85.1, C86.2, C87.2, C89.2, C90.1, C92.1, C93.2, C94.2, Q1.2 (S), R13.1, R16.1, R17.1, R19.1, R21.2, R26.1, R27.1, R28.2, U3.2 (GND), U4.2 (GND), U5.2 (GND), U6.2 (GND), U7.2 (GND), U8.2 (GND); also elsewhere on the board
unnamed: Q1.3 (D), R22.2
unnamed: C94.1, Q1.1 (G), R23.2, R24.1
unnamed: Q2.3 (D), R28.1, U8.1 (EN)
unnamed: C61.2, R12.1, R13.2, U3.5 (FB)
unnamed: L1.1, U3.3 (LX)
unnamed: C66.2, R14.1, R16.2, U4.5 (FB)
unnamed: L2.1, U4.3 (LX)
unnamed: C71.2, R15.1, R17.2, U5.5 (FB)
unnamed: L3.1, U5.3 (LX)
unnamed: C77.2, R18.1, R19.2, U6.5 (FB)
unnamed: L4.1, U6.3 (LX)
unnamed: C81.2, U7.1 (BS)
unnamed: C88.2, R20.2, R21.1, R22.1, U7.3 (FB)
unnamed: C81.1, L5.1, U7.6 (LX)
unnamed: C91.2, R25.1, R26.2, U8.5 (FB)
unnamed: L6.1, U8.3 (LX)

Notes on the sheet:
SYSTEM 1.2V/2A Vout=0.6*(1+R1/R2) Vout=0.6*(1+100/100)=1.2V
WIFI 3.3V/1A Vout=0.6*(1+R1/R2) Vout=0.6*(1+10/2.21)=3.3V
0.6*(30/6.8+1)=3.3? 0.6*(150/33+1)=3.3?
RTC 3.3V/0.5A Vout=0.6*(1+R1/R2) Vout=0.6*(1+10/2.21)=3.3V
IO 3.3V/1A Vout=0.6*(1+R1/R2) Vout=0.6*(1+10/2.21)=3.3V
CPU 1.1V/3A Vout=0.6*(1+10/11.8)=1.1V Vout=0.6*(1+10/((11.8*30.1)/(11.8+30.1)))=1.3V
DRAM 1.5V/1A Vout=0.6*(1+R1/R2) Vout=0.6*(1+15/10)=1.5V
Bigger unique L?
SY8088AAC (C79313) can be replaced with SY8088A (C41348272), but has worse quiescent current :c SY8089AAAC (C78988) can also be replaced with SY8089A1AAC (C479074) or SY8089A (C41348273) for worse specs SY8113 has I (C479075) and B (C78989) varients, we are choosing I for lower quiescent and higher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
Inductors: Less than 100mΩ resistance L=(Vout*(1-Vout/Vin))/(Fsw*Iout*0.4)

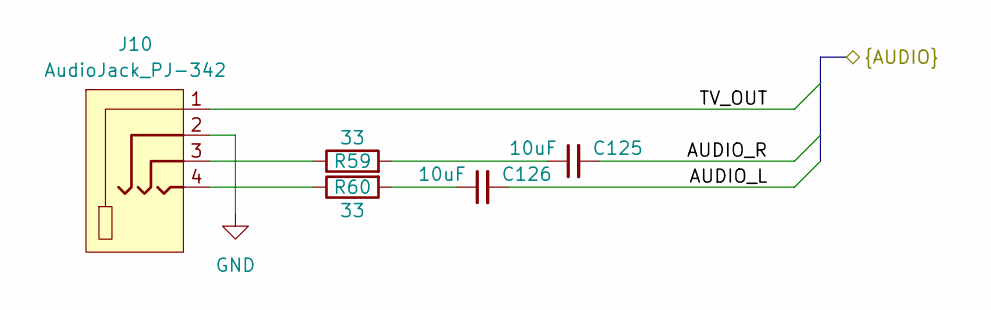
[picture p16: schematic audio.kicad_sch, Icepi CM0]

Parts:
C125, C126: 10uF; C_0603_1608Metric; LCSC Part # C19702
J10: AudioJack_PJ-342; Jack_3.5mm_SHOUHAN_PJ-342; LCSC Part # C7507452
R59, R60: 33; R_0402_1005Metric; LCSC Part # C25105

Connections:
/Audio/AUDIO_L: C126.2; also elsewhere on the board
/Audio/AUDIO_R: C125.2; also elsewhere on the board
/Audio/TV_OUT: J10.1; also elsewhere on the board
GND: J10.2; also elsewhere on the board
unnamed: C125.1, R59.2
unnamed: C126.1, R60.2
unnamed: J10.3, J10.5, R59.1
unnamed: J10.4, J10.6, R60.1

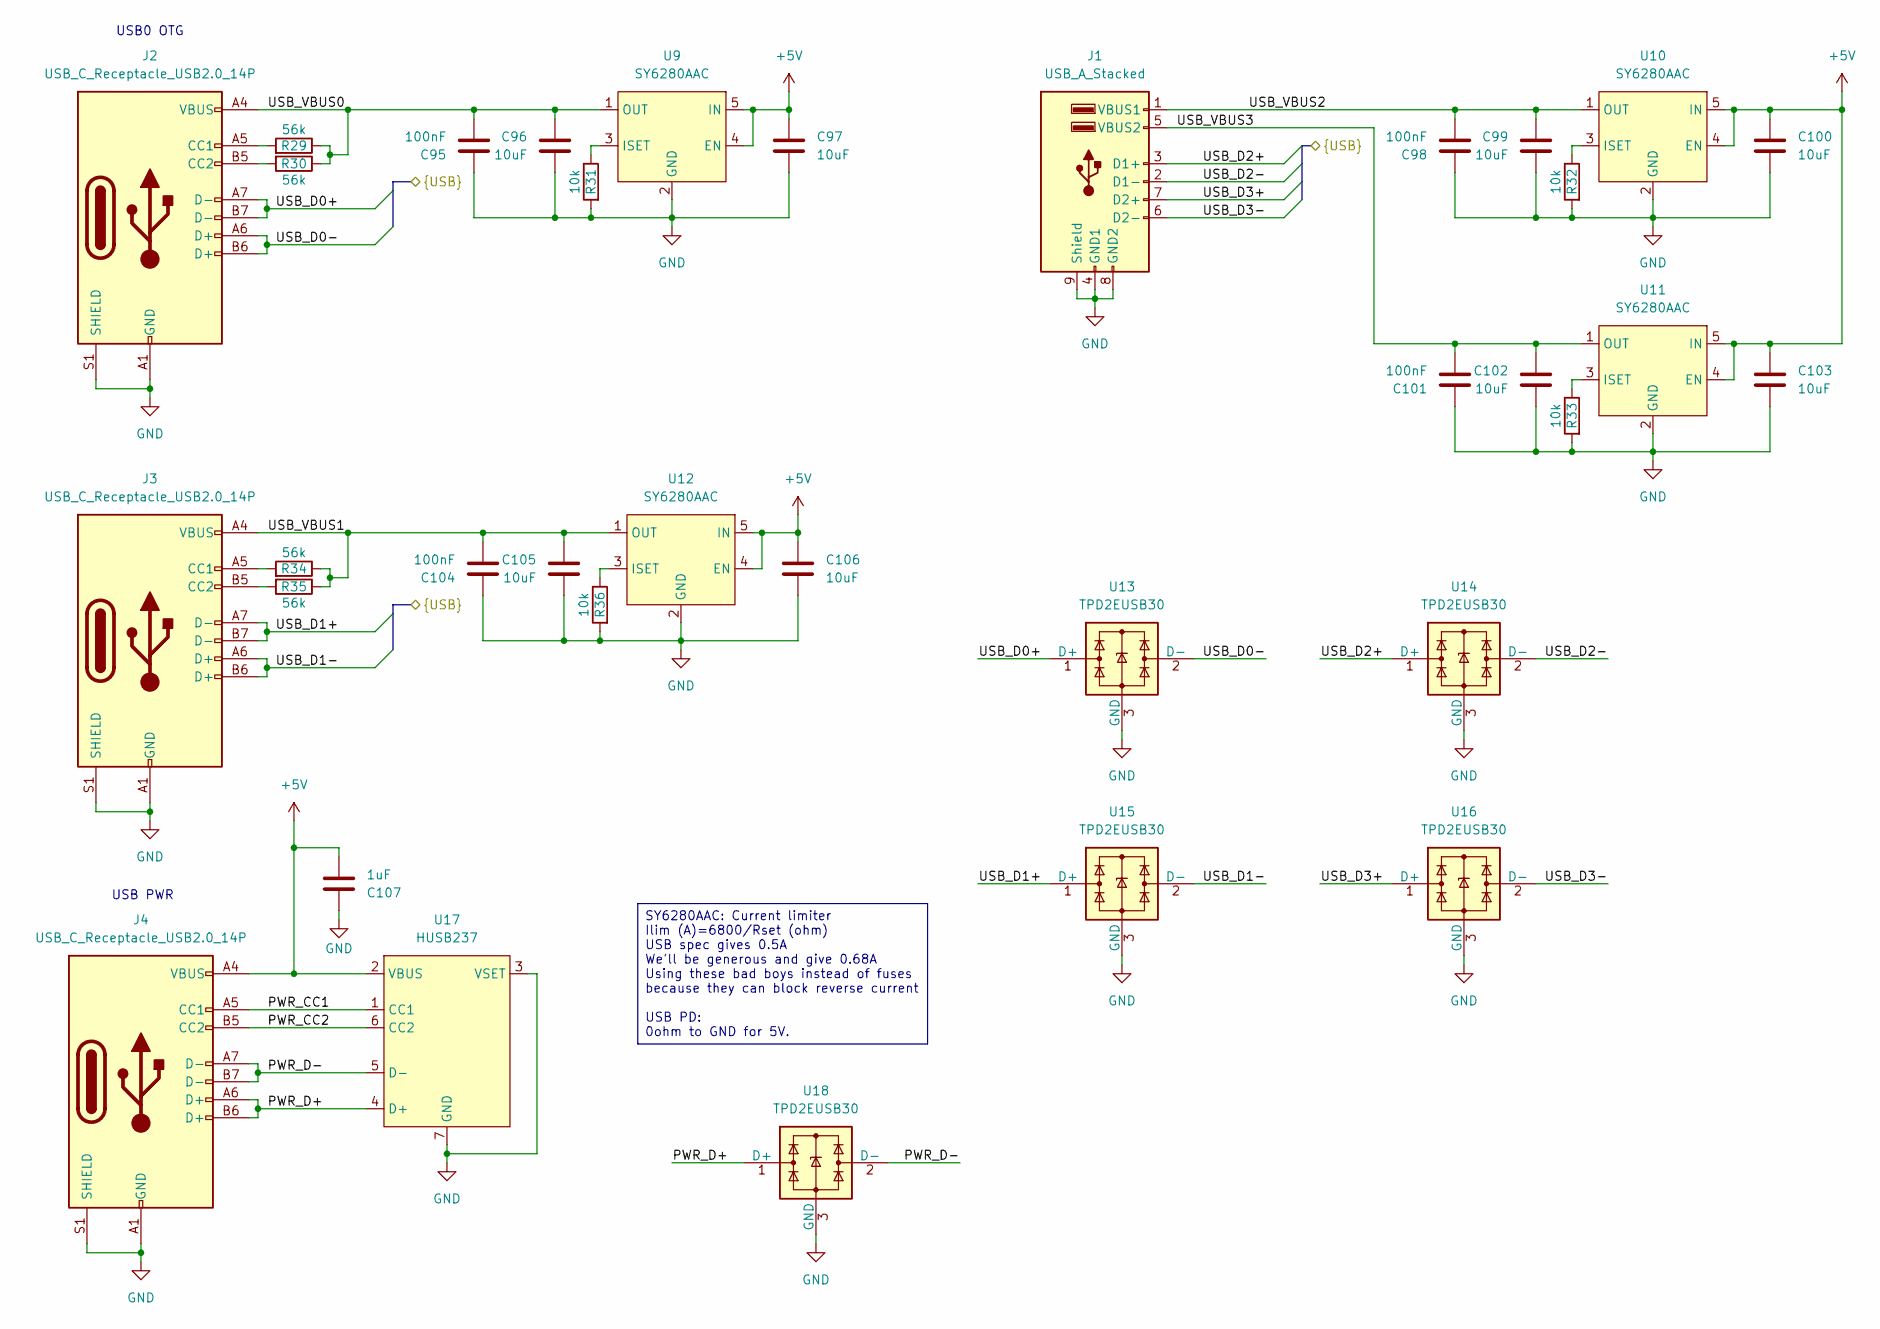
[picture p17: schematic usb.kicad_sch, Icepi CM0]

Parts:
C95, C98, C101, C104: 100nF; C_0402_1005Metric; LCSC Part # C1525
C96, C97, C99, C100, C102, C103, C105, C106: 10uF; C_0603_1608Metric; LCSC Part # C19702
C107: 1uF; C_0402_1005Metric; LCSC Part # C52923
J1: USB_A_Stacked; USB_A_SHOUHAN_AF_SS-JB17.6_Horizontal_Stacked; LCSC Part # C456021
J2, J3, J4: USB_C_Receptacle_USB2.0_14P; USB_C_Receptacle_HRO_TYPE-C-31-M-12; LCSC Part # C165948
R29, R30, R34, R35: 56k; R_0402_1005Metric; LCSC Part # C25796
R31, R32, R33, R36: 10k; R_0402_1005Metric; LCSC Part # C25744
U9, U10, U11, U12: SY6280AAC; SOT-23-5; LCSC Part # C55136
U13, U14, U15, U16, U18: TPD2EUSB30; Texas_DRT-3; LCSC Part # C5182099
U17: HUSB237; DFN-6-1EP_2x2mm_P0.65mm_EP1x1.6mm; LCSC Part # C22373734

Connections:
+5V: C97.1, C100.1, C103.1, C106.1, C107.2, J4.A4 (VBUS), J4.A9 (VBUS), J4.B4 (VBUS), J4.B9 (VBUS), U9.4 (EN), U9.5 (IN), U10.4 (EN), U10.5 (IN), U11.4 (EN), U11.5 (IN), U12.4 (EN), U12.5 (IN), U17.2 (VBUS); also elsewhere on the board
/H3/USB_D0+: J2.A7 (D-), J2.B7 (D-), U13.1 (D+); also elsewhere on the board
/H3/USB_D0-: J2.A6 (D+), J2.B6 (D+), U13.2 (D-); also elsewhere on the board
/H3/USB_D1+: J3.A7 (D-), J3.B7 (D-), U15.1 (D+); also elsewhere on the board
/H3/USB_D1-: J3.A6 (D+), J3.B6 (D+), U15.2 (D-); also elsewhere on the board
/USB/PWR_CC1: J4.A5 (CC1), U17.1 (CC1)
/USB/PWR_CC2: J4.B5 (CC2), U17.6 (CC2)
/USB/PWR_D+: J4.A6 (D+), J4.B6 (D+), U17.4 (D+), U18.1 (D+)
/USB/PWR_D-: J4.A7 (D-), J4.B7 (D-), U17.5 (D-), U18.2 (D-)
/USB/USB_VBUS0: C95.2, C96.1, J2.A4 (VBUS), J2.A9 (VBUS), J2.B4 (VBUS), J2.B9 (VBUS), R29.1, R30.1, U9.1 (OUT)
/USB/USB_VBUS1: C104.2, C105.1, J3.A4 (VBUS), J3.A9 (VBUS), J3.B4 (VBUS), J3.B9 (VBUS), R34.1, R35.1, U12.1 (OUT)
/USB/USB_VBUS2: C98.2, C99.1, J1.1 (VBUS1), U10.1 (OUT)
/USB/USB_VBUS3: C101.2, C102.1, J1.5 (VBUS2), U11.1 (OUT)
GND: C95.1, C96.2, C97.2, C98.1, C99.2, C100.2, C101.1, C102.2, C103.2, C104.1, C105.2, C106.2, C107.1, J1.4 (GND1), J1.8 (GND2), J1.9 (Shield), J2.A1 (GND), J2.A12 (GND), J2.B1 (GND), J2.B12 (GND), J2.S1 (SHIELD), J3.A1 (GND), J3.A12 (GND), J3.B1 (GND), J3.B12 (GND), J3.S1 (SHIELD), J4.A1 (GND), J4.A12 (GND), J4.B1 (GND), J4.B12 (GND), J4.S1 (SHIELD), R31.2, R32.2, R33.2, R36.2, U9.2 (GND), U10.2 (GND), U11.2 (GND), U12.2 (GND), U13.3 (GND), U14.3 (GND), U15.3 (GND), U16.3 (GND), U17.3 (VSET), U17.7 (GND), U18.3 (GND); also elsewhere on the board
unnamed: J2.A5 (CC1), R29.2
unnamed: J2.B5 (CC2), R30.2
unnamed: J3.A5 (CC1), R34.2
unnamed: J3.B5 (CC2), R35.2
unnamed: R31.1, U9.3 (ISET)
unnamed: R32.1, U10.3 (ISET)
unnamed: R33.1, U11.3 (ISET)
unnamed: R36.1, U12.3 (ISET)

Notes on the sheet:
USB0 OTG
USB PWR
SY6280AAC: Current limiter Ilim (A)=6800/Rset (ohm) USB spec gives 0.5A We'll be generous and give 0.68A Using these bad boys instead of fuses because they can block reverse current USB PD: 0ohm to GND for 5V.

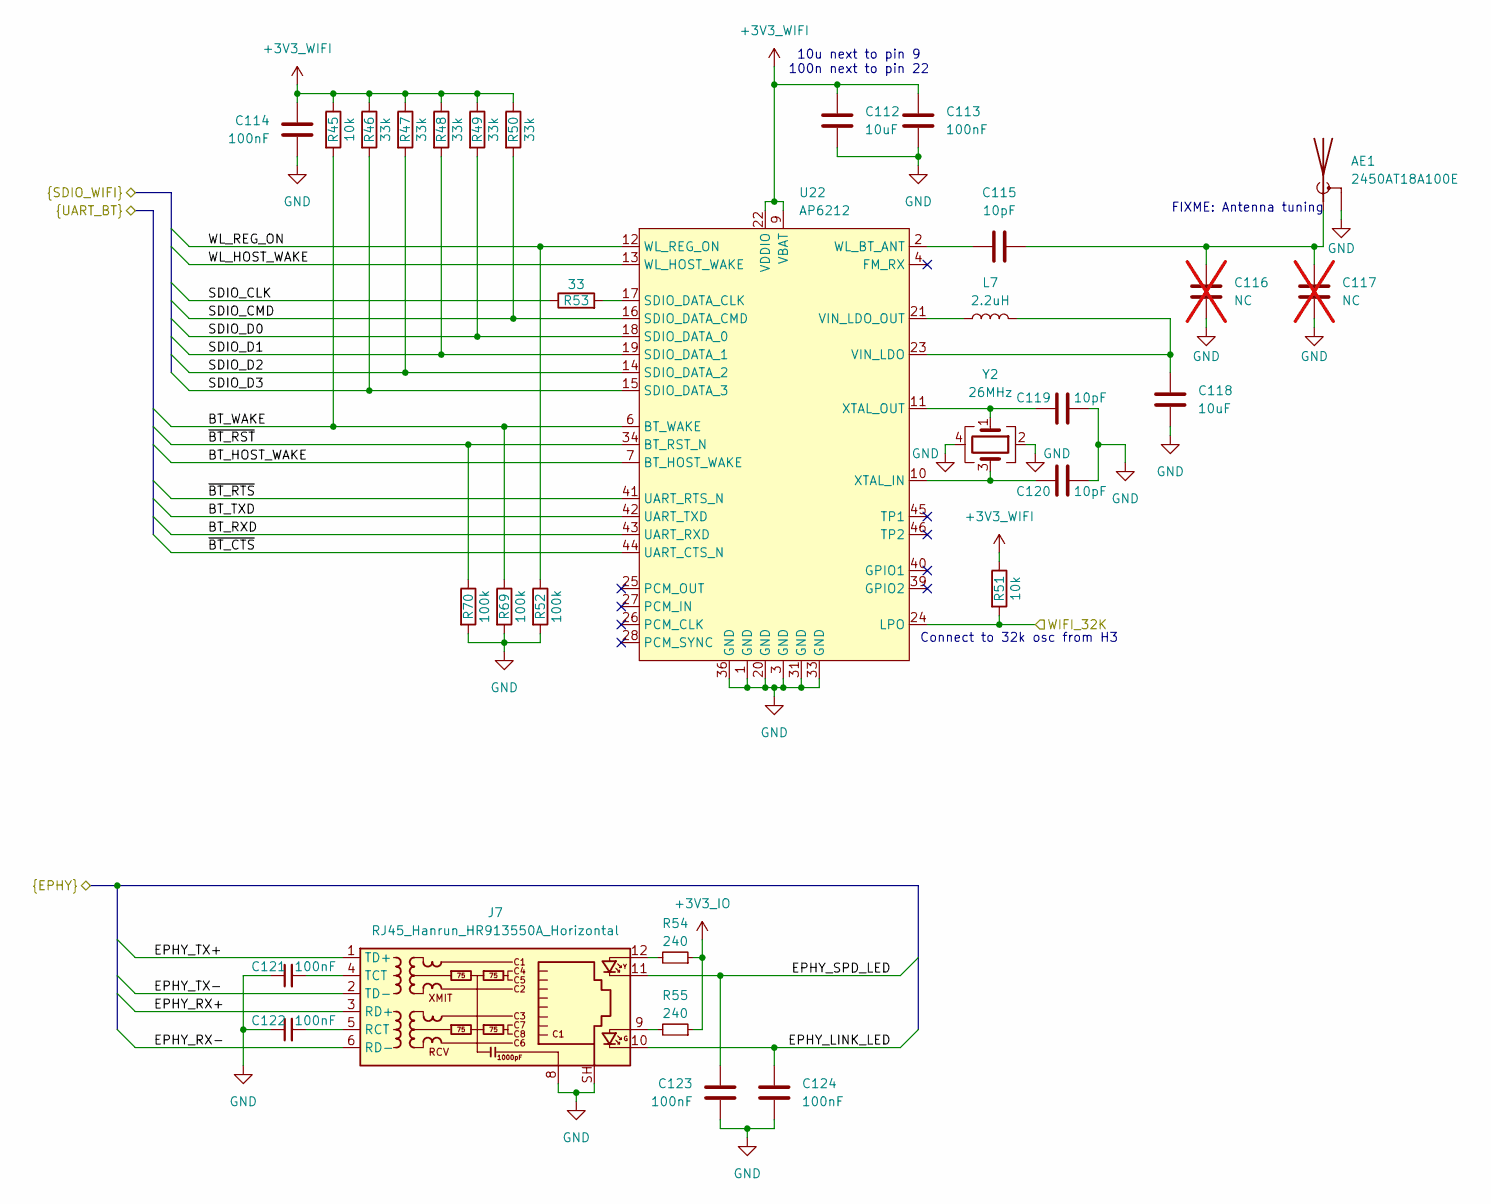
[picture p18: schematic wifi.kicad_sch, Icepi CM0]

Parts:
AE1: 2450AT18A100E; Johanson_2450AT18x100; LCSC Part # C89334
C112, C118: 10uF; C_0603_1608Metric; LCSC Part # C19702
C113, C114, C121, C122, C123, C124: 100nF; C_0402_1005Metric; LCSC Part # C1525
C115, C119, C120: 10pF; C_0402_1005Metric; LCSC Part # C32949
C116, C117: NC; C_0402_1005Metric; not fitted
J7: RJ45_Hanrun_HR913550A_Horizontal; RJ45_Hanrun_HR911105A_Horizontal; LCSC Part # C163507
L7: 2.2uH; L_Sunlord_SWPA3015S; LCSC Part # C19734
R45, R51: 10k; R_0402_1005Metric; LCSC Part # C25744
R46, R47, R48, R49, R50: 33k; R_0402_1005Metric; LCSC Part # C25779
R52, R69, R70: 100k; R_0402_1005Metric; LCSC Part # C25741
R53: 33; R_0402_1005Metric; LCSC Part # C25105
R54, R55: 240; R_0603_1608Metric; LCSC Part # C23350
U22: AP6212; LCSC Part # C2798300
Y2: 26MHz; Crystal_SMD_2016-4Pin_2.0x1.6mm; LCSC Part # C7294683

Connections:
+3V3_IO: R54.1, R55.1; also elsewhere on the board
+3V3_WIFI: C112.1, C113.1, C114.1, R45.1, R46.1, R47.1, R48.1, R49.1, R50.1, R51.1, U22.9 (VBAT), U22.22 (VDDIO); also elsewhere on the board
/H3/BT_HOST_WAKE: U22.7 (BT_HOST_WAKE); also elsewhere on the board
/H3/BT_RXD: U22.43 (UART_RXD); also elsewhere on the board
/H3/BT_TXD: U22.42 (UART_TXD); also elsewhere on the board
/H3/BT_WAKE: R45.2, R69.1, U22.6 (BT_WAKE); also elsewhere on the board
/H3/EPHY_LINK_LED: C124.1, J7.10; also elsewhere on the board
/H3/EPHY_RX+: J7.3 (RD+); also elsewhere on the board
/H3/EPHY_RX-: J7.6 (RD-); also elsewhere on the board
/H3/EPHY_SPD_LED: C123.1, J7.11; also elsewhere on the board
/H3/EPHY_TX+: J7.1 (TD+); also elsewhere on the board
/H3/EPHY_TX-: J7.2 (TD-); also elsewhere on the board
/H3/SDIO_CLK: R53.1; also elsewhere on the board
/H3/SDIO_CMD: R50.2, U22.16 (SDIO_DATA_CMD); also elsewhere on the board
/H3/SDIO_D0: R49.2, U22.18 (SDIO_DATA_0); also elsewhere on the board
/H3/SDIO_D1: R48.2, U22.19 (SDIO_DATA_1); also elsewhere on the board
/H3/SDIO_D2: R47.2, U22.14 (SDIO_DATA_2); also elsewhere on the board
/H3/SDIO_D3: R46.2, U22.15 (SDIO_DATA_3); also elsewhere on the board
/H3/WIFI_32K: R51.2, U22.24 (LPO); also elsewhere on the board
/H3/WL_HOST_WAKE: U22.13 (WL_HOST_WAKE); also elsewhere on the board
/H3/WL_REG_ON: R52.1, U22.12 (WL_REG_ON); also elsewhere on the board
/H3/~BT_CTS: U22.44 (UART_CTS_N); also elsewhere on the board
/H3/~BT_RST: R70.1, U22.34 (BT_RST_N); also elsewhere on the board
/H3/~BT_RTS: U22.41 (UART_RTS_N); also elsewhere on the board
GND: AE1.2 (Shield), C112.2, C113.2, C114.2, C116.2, C117.2, C118.2, C119.2, C120.2, C121.1, C122.1, C123.2, C124.2, J7.8, J7.SH, R52.2, R69.2, R70.2, U22.1 (GND), U22.3 (GND), U22.20 (GND), U22.31 (GND), U22.33 (GND), U22.36 (GND), Y2.2, Y2.4; also elsewhere on the board
unnamed: AE1.1 (A), C115.2, C116.1, C117.1
unnamed: J7.9, R55.2
unnamed: J7.12, R54.2
unnamed: C122.2, J7.5 (RCT)
unnamed: C121.2, J7.4 (TCT)
unnamed: R53.2, U22.17 (SDIO_DATA_CLK)
unnamed: C118.1, L7.2, U22.23 (VIN_LDO)
unnamed: L7.1, U22.21 (VIN_LDO_OUT)
unnamed: C115.1, U22.2 (WL_BT_ANT)
unnamed: C120.1, U22.10 (XTAL_IN), Y2.3
unnamed: C119.1, U22.11 (XTAL_OUT), Y2.1

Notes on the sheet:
FIXME: Antenna tuning
10u next to pin 9 100n next to pin 22
Connect to 32k osc from H3

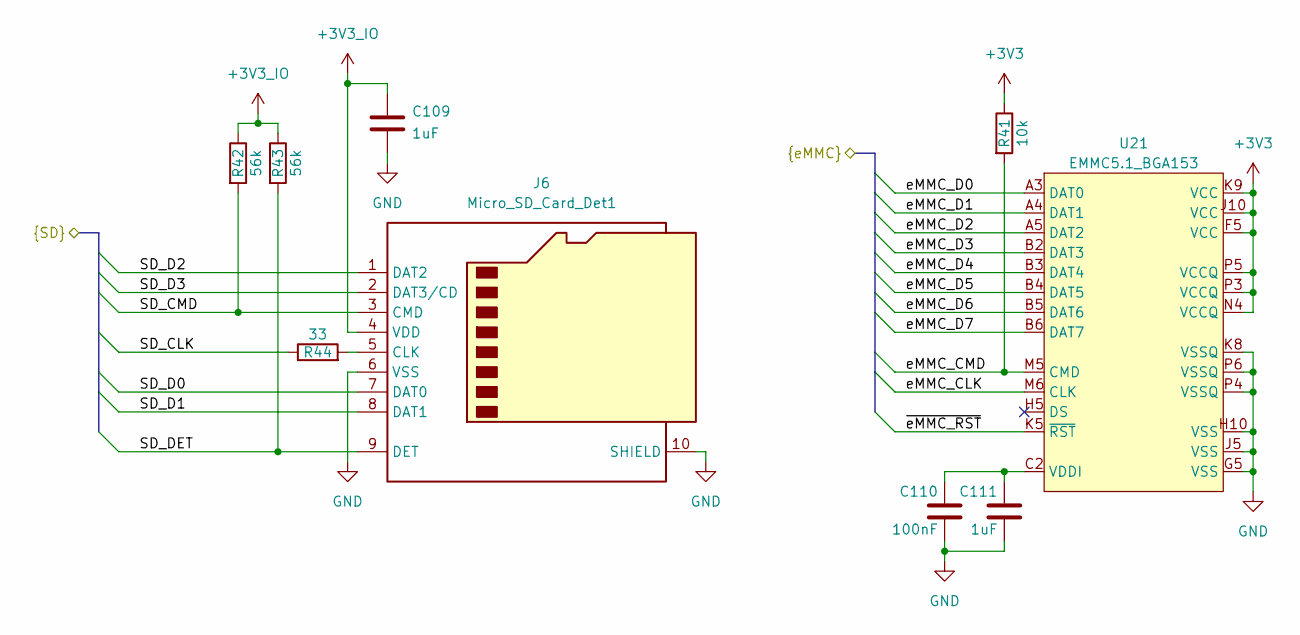
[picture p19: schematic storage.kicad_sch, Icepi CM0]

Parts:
C109, C111: 1uF; C_0402_1005Metric; LCSC Part # C52923
C110: 100nF; C_0402_1005Metric; LCSC Part # C1525
J6: Micro_SD_Card_Det1; microSD_TF-01A; LCSC Part # C2889258
R41: 10k; R_0402_1005Metric; LCSC Part # C25744
R42, R43: 56k; R_0402_1005Metric; LCSC Part # C25796
R44: 33; R_0402_1005Metric; LCSC Part # C25105
U21: EMMC5.1_BGA153; LFBGA-153_11.5x13mm_Layout14x14_P0.5mm

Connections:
+3V3: R41.1, U21.C6 (VCCQ), U21.E6 (VCC), U21.F5 (VCC), U21.J10 (VCC), U21.K9 (VCC), U21.M4 (VCCQ), U21.N4 (VCCQ), U21.P3 (VCCQ), U21.P5 (VCCQ); also elsewhere on the board
+3V3_IO: C109.2, J6.4 (VDD), R42.1, R43.1; also elsewhere on the board
/H3/SD_CLK: R44.1; also elsewhere on the board
/H3/SD_CMD: J6.3 (CMD), R42.2; also elsewhere on the board
/H3/SD_D0: J6.7 (DAT0); also elsewhere on the board
/H3/SD_D1: J6.8 (DAT1); also elsewhere on the board
/H3/SD_D2: J6.1 (DAT2); also elsewhere on the board
/H3/SD_D3: J6.2 (DAT3/CD); also elsewhere on the board
/H3/SD_DET: J6.9 (DET), R43.2; also elsewhere on the board
/H3/eMMC_CLK: U21.M6 (CLK); also elsewhere on the board
/H3/eMMC_CMD: R41.2, U21.M5 (CMD); also elsewhere on the board
/H3/eMMC_D0: U21.A3 (DAT0); also elsewhere on the board
/H3/eMMC_D1: U21.A4 (DAT1); also elsewhere on the board
/H3/eMMC_D2: U21.A5 (DAT2); also elsewhere on the board
/H3/eMMC_D3: U21.B2 (DAT3); also elsewhere on the board
/H3/eMMC_D4: U21.B3 (DAT4); also elsewhere on the board
/H3/eMMC_D5: U21.B4 (DAT5); also elsewhere on the board
/H3/eMMC_D6: U21.B5 (DAT6); also elsewhere on the board
/H3/eMMC_D7: U21.B6 (DAT7); also elsewhere on the board
/H3/~eMMC_RST: U21.K5 (~RST); also elsewhere on the board
GND: C109.1, C110.2, C111.1, J6.6 (VSS), J6.10 (SHIELD), U21.A6 (VSS), U21.C4 (VSSQ), U21.E7 (VSS), U21.G5 (VSS), U21.H10 (VSS), U21.J5 (VSS), U21.K8 (VSSQ), U21.N2 (VSSQ), U21.N5 (VSSQ), U21.P4 (VSSQ), U21.P6 (VSSQ); also elsewhere on the board
unnamed: J6.5 (CLK), R44.2
unnamed: C110.1, C111.2, U21.C2 (VDDI)

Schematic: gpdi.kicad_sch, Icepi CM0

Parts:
C108: 100nF; C_0402_1005Metric; LCSC Part # C1525
D1, D2: 1N5819WS; D_SOD-323; LCSC Part # C191023
J5: GPDI_A; GPDI_A_XUNPU_001S; LCSC Part # C720616
Q3: BSN20; SOT-23; LCSC Part # C116157
R37, R38: 33k; R_0402_1005Metric; LCSC Part # C25779
R39, R40: 2k; R_0402_1005Metric; LCSC Part # C4109
U19, U20, U23: UCL0524P; Diodes_UDFN-10_1.0x2.5mm_P0.5mm; LCSC Part # C2835428

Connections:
+3V3: D1.2 (A), Q3.1 (G), R37.1; also elsewhere on the board
+5V: D2.2 (A), R39.2, R40.2; also elsewhere on the board
/GPDI/GPDI_CEC: Q3.2 (S), R37.2; also elsewhere on the board
/GPDI/GPDI_CECI: J5.13 (CEC), Q3.3 (D), R38.2, U23.1, U23.10
/GPDI/GPDI_CLK+: J5.10 (CK+), U20.4, U20.7; also elsewhere on the board
/GPDI/GPDI_CLK-: J5.12 (CK-), U20.5, U20.6; also elsewhere on the board
/GPDI/GPDI_D0+: J5.7 (D0+), U20.1, U20.10; also elsewhere on the board
/GPDI/GPDI_D0-: J5.9 (D0-), U20.2, U20.9; also elsewhere on the board
/GPDI/GPDI_D1+: J5.4 (D1+), U19.4, U19.7; also elsewhere on the board
/GPDI/GPDI_D1-: J5.6 (D1-), U19.5, U19.6; also elsewhere on the board
/GPDI/GPDI_D2+: J5.1 (D2+), U19.1, U19.10; also elsewhere on the board
/GPDI/GPDI_D2-: J5.3 (D2-), U19.2, U19.9; also elsewhere on the board
/GPDI/GPDI_HPD: J5.19 (HPD), U23.5, U23.6; also elsewhere on the board
/GPDI/GPDI_SCL: J5.15 (SCL), R40.1, U23.2, U23.9; also elsewhere on the board
/GPDI/GPDI_SDA: J5.16 (SDA), R39.1, U23.4, U23.7; also elsewhere on the board
GND: C108.1, J5.2 (D2S), J5.5 (D1S), J5.8 (D0S), J5.11 (CKS), J5.17 (GND), J5.SH, U19.3, U19.8, U20.3, U20.8, U23.3, U23.8; also elsewhere on the board
unnamed: D1.1 (K), R38.1
unnamed: C108.2, D2.1 (K), J5.18 (+5V)

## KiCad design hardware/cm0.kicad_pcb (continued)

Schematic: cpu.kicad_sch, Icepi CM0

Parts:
C1, C2, C3, C4, C7, C8, C9, C12, C14, C18, C19, C23, C24, C26, C27, C29, C31, C37, C38, C130: 100nF; C_0402_1005Metric; LCSC Part # C1525
C10, C11, C32, C129: 4.7uF; C_0402_1005Metric; LCSC Part # C23733
C13, C16, C17, C21, C22, C25, C33, C35, C36: 1uF; C_0402_1005Metric; LCSC Part # C52923
C15, C20, C28, C30: 10uF; C_0603_1608Metric; LCSC Part # C19702
C34, C39, C127, C128: 15pF; C_0402_1005Metric; LCSC Part # C1548
Q5: MMBT3904; SOT-23; LCSC Part # C20526
R1: 6.04k; R_0402_1005Metric; LCSC Part # C25913
R2: 240; R_0603_1608Metric; LCSC Part # C23350
R3, R5: 0; R_0402_1005Metric; LCSC Part # C17168
R4: 220k; R_0402_1005Metric; LCSC Part # C25767
R6: 10M; R_0402_1005Metric; LCSC Part # C26082
R61, R66, R67, R68: 47k; R_0402_1005Metric; LCSC Part # C25792
R62: 100k; R_0402_1005Metric; LCSC Part # C25741
R63, R64, R65: 10k; R_0402_1005Metric; LCSC Part # C25744
TP1, TP2, TP3: TestPoint; TestPoint_Pad_D1.0mm; not fitted
U1: H3; FBGA-347_14x14mm_Layout21x21_P0.65mm; LCSC Part # C94644
Y1: 32kHz; Crystal_SMD_3215-2Pin_3.2x1.5mm; LCSC Part # C32346
Y3: 24MHz; Crystal_SMD_2016-4Pin_2.0x1.6mm; LCSC Part # C362340

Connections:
+1V1_CPUX: C15.1, C16.2, C17.2, C18.2, C19.2, U1.N8 (VDD-CPUX), U1.P6 (VDD-CPUX), U1.P7 (VDD-CPUX), U1.P8 (VDD-CPUX), U1.P9 (VDD-CPUX), U1.R6 (VDD-CPUX), U1.R7 (VDD-CPUX), U1.R8 (VDD-CPUX), U1.T6 (VDD-CPUX), U1.T7 (VDD-CPUX), U1.T8 (VDD-CPUX), U1.U6 (VDD-CPUX), U1.U9 (VDD-CPUX); also elsewhere on the board
+1V2_SYSTEM: C4.2, C20.1, C21.2, C22.2, C23.2, C24.2, U1.F8 (EPHY_VDD), U1.H10 (VDD-SYS), U1.J10 (VDD-SYS), U1.J11 (VDD-SYS), U1.J12 (VDD-SYS), U1.K10 (VDD-SYS), U1.K11 (VDD-SYS), U1.K12 (VDD-SYS), U1.L10 (VDD-SYS), U1.L11 (VDD-SYS), U1.L12 (VDD-SYS), U1.L13 (VDD-SYS), U1.L14 (VDD-SYS); also elsewhere on the board
+1V5: C35.2, C36.2, C37.2, C38.2, U1.L16 (VCC-DRAM), U1.M16 (VCC-DRAM), U1.N16 (VCC-DRAM), U1.P16 (VCC-DRAM), U1.P17 (VCC-DRAM), U1.R16 (VCC-DRAM), U1.T12 (VCC-DRAM), U1.T13 (VCC-DRAM), U1.T14 (VCC-DRAM), U1.T15 (VCC-DRAM), U1.U11 (VCC-DRAM); also elsewhere on the board
+3V3_AVCC: C7.2, C12.2, C27.2, C28.1, C29.2, R61.1, R62.1, R65.1, R66.1, R68.1, U1.G9 (V33_TV), U1.K6 (VCC_RTC), U1.N3 (VCC_PLL), U1.V3 (AVCC); also elsewhere on the board
+3V3_IO: C1.2, C2.2, C3.2, C8.2, C13.2, C14.2, C129.1, R67.1, U1.G7 (EPHY_VCC), U1.G11 (VCC_USB), U1.G13 (VCC-IO), U1.G14 (VCC-IO), U1.G15 (VCC-IO), U1.H7 (VCC-PG), U1.H11 (VDD-EFUSEEBP), U1.H13 (VCC-IO), U1.H14 (VCC-IO), U1.J6 (GPDI_VCC), U1.J14 (VCC-IO), U1.J15 (VCC_PD); also elsewhere on the board
/Audio/AUDIO_L: U1.AA3 (LINEOUTL); also elsewhere on the board
/Audio/AUDIO_R: U1.Y3 (LINEOUTR); also elsewhere on the board
/Audio/TV_OUT: U1.F10 (TVOUT); also elsewhere on the board
/DDR3/A0: U1.T17 (SA0); also elsewhere on the board
/DDR3/A1: U1.U18 (SA1); also elsewhere on the board
/DDR3/A2: U1.V19 (SA2); also elsewhere on the board
/DDR3/A3: U1.V20 (SA3); also elsewhere on the board
/DDR3/A4: U1.V21 (SA4); also elsewhere on the board
/DDR3/A5: U1.Y19 (SA5); also elsewhere on the board
/DDR3/A6: U1.Y20 (SA6); also elsewhere on the board
/DDR3/A7: U1.V15 (SA7); also elsewhere on the board
/DDR3/A8: U1.W18 (SA8); also elsewhere on the board
/DDR3/A9: U1.Y18 (SA9); also elsewhere on the board
/DDR3/A10: U1.P19 (SA10); also elsewhere on the board
/DDR3/A11: U1.N19 (SA11); also elsewhere on the board
/DDR3/A12: U1.R18 (SA12); also elsewhere on the board
/DDR3/A13: U1.V12 (SA13); also elsewhere on the board
/DDR3/A14: U1.N17 (SA14); also elsewhere on the board
/DDR3/A15: U1.R17 (SA15); also elsewhere on the board
/DDR3/BA0: U1.W17 (SBA0); also elsewhere on the board
/DDR3/BA1: U1.T18 (SBA1); also elsewhere on the board
/DDR3/BA2: U1.V17 (SBA2); also elsewhere on the board
/DDR3/CKE: U1.AA21 (SCKE0); also elsewhere on the board
/DDR3/CLK+: U1.AA19 (SCK); also elsewhere on the board
/DDR3/CLK-: U1.AA20 (SCKB); also elsewhere on the board
/DDR3/DQ0: U1.T20 (SDQ5); also elsewhere on the board
/DDR3/DQ1: U1.P20 (SDQ2); also elsewhere on the board
/DDR3/DQ2: U1.U19 (SDQ6); also elsewhere on the board
/DDR3/DQ3: U1.N20 (SDQ0); also elsewhere on the board
/DDR3/DQ4: U1.U20 (SDQ7); also elsewhere on the board
/DDR3/DQ5: U1.P21 (SDQ1); also elsewhere on the board
/DDR3/DQ6: U1.U21 (SDQ3); also elsewhere on the board
/DDR3/DQ7: U1.R19 (SDQ4); also elsewhere on the board
/DDR3/DQ8: U1.J21 (SDQ11); also elsewhere on the board
/DDR3/DQ9: U1.M21 (SDQ14); also elsewhere on the board
/DDR3/DQ10: U1.H21 (SDQ10); also elsewhere on the board
/DDR3/DQ11: U1.M19 (SDQ15); also elsewhere on the board
/DDR3/DQ12: U1.J19 (SDQ8); also elsewhere on the board
/DDR3/DQ13: U1.L21 (SDQ13); also elsewhere on the board
/DDR3/DQ14: U1.H20 (SDQ9); also elsewhere on the board
/DDR3/DQ15: U1.L20 (SDQ12); also elsewhere on the board
/DDR3/DQ16: U1.Y17 (SDQ16)
/DDR3/DQ17: U1.AA17 (SDQ17)
/DDR3/DQ18: U1.Y16 (SDQ18)
/DDR3/DQ19: U1.W15 (SDQ19)
/DDR3/DQ20: U1.Y14 (SDQ20)
/DDR3/DQ21: U1.AA14 (SDQ21)
/DDR3/DQ22: U1.Y13 (SDQ22)
/DDR3/DQ23: U1.Y12 (SDQ23)
/DDR3/DQ24: U1.W12 (SDQ24)
/DDR3/DQ25: U1.AA11 (SDQ25)
/DDR3/DQ26: U1.Y11 (SDQ26)
/DDR3/DQ27: U1.Y10 (SDQ27)
/DDR3/DQ28: U1.W9 (SDQ28)
/DDR3/DQ29: U1.AA8 (SDQ29)
/DDR3/DQ30: U1.Y8 (SDQ30)
/DDR3/DQ31: U1.Y7 (SDQ31)
/DDR3/DQM0: U1.M20 (SDQM0); also elsewhere on the board
/DDR3/DQM1: U1.G20 (SDQM1); also elsewhere on the board
/DDR3/DQM2: U1.AA18 (SDQM2)
/DDR3/DQM3: U1.AA12 (SDQM3)
/DDR3/DQS0+: U1.R20 (SDQS0); also elsewhere on the board
/DDR3/DQS0-: U1.R21 (SDQS0B); also elsewhere on the board
/DDR3/DQS1+: U1.K20 (SDQS1); also elsewhere on the board
/DDR3/DQS1-: U1.J20 (SDQS1B); also elsewhere on the board
/DDR3/DQS2+: U1.AA15 (SDQS2)
/DDR3/DQS2-: U1.Y15 (SDQS2B)
/DDR3/DQS3+: U1.AA9 (SDQS3)
/DDR3/DQS3-: U1.Y9 (SDQS3B)
/DDR3/ODT: U1.W11 (SODT0); also elsewhere on the board
/DDR3/~CAS: U1.U15 (SCAS); also elsewhere on the board
/DDR3/~CS: U1.W20 (SCS0); also elsewhere on the board
/DDR3/~RAS: U1.V13 (SRAS); also elsewhere on the board
/DDR3/~RESET: U1.U16 (SRST); also elsewhere on the board
/DDR3/~WE: U1.W13 (SWE); also elsewhere on the board
/GPDI/GPDI_CEC: U1.G5 (GPDI_CEC); also elsewhere on the board
/GPDI/GPDI_CLK+: U1.F2 (GPDI_CLK+); also elsewhere on the board
/GPDI/GPDI_CLK-: U1.E2 (GPDI_CLK-); also elsewhere on the board
/GPDI/GPDI_D0+: U1.G1 (GPDI_D0+); also elsewhere on the board
/GPDI/GPDI_D0-: U1.F1 (GPDI_D0-); also elsewhere on the board
/GPDI/GPDI_D1+: U1.H2 (GPDI_D1+); also elsewhere on the board
/GPDI/GPDI_D1-: U1.G2 (GPDI_D1-); also elsewhere on the board
/GPDI/GPDI_D2+: U1.J1 (GPDI_D2+); also elsewhere on the board
/GPDI/GPDI_D2-: U1.J2 (GPDI_D2-); also elsewhere on the board
/GPDI/GPDI_HPD: U1.M2 (GPDI_HPD); also elsewhere on the board
/GPDI/GPDI_SCL: U1.H3 (GPDI_SCL); also elsewhere on the board
/GPDI/GPDI_SDA: U1.K3 (GPDI_SDA); also elsewhere on the board
/GPIO/CPU_RX: U1.H6 (PA5); also elsewhere on the board
/GPIO/CPU_TX: U1.F5 (PA4); also elsewhere on the board
/H3/AGND: C28.2, C29.1, C30.2, C31.1, C32.2, C33.1, R4.2, R5.1, U1.U3 (AGND)
/H3/BT_HOST_WAKE: U1.P2 (PL2); also elsewhere on the board
/H3/BT_RXD: U1.D3 (UART1_RX); also elsewhere on the board
/H3/BT_TXD: U1.G4 (UART1_TX); also elsewhere on the board
/H3/BT_WAKE: U1.A13 (PA20); also elsewhere on the board
/H3/EPHY_LINK_LED: U1.A2 (EPHY_LINK_LED); also elsewhere on the board
/H3/EPHY_RX+: U1.B4 (EPHY_RXP); also elsewhere on the board
/H3/EPHY_RX-: U1.A4 (EPHY_RXN); also elsewhere on the board
/H3/EPHY_SPD_LED: U1.F7 (EPHY_SPD_LED); also elsewhere on the board
/H3/EPHY_TX+: U1.B3 (EPHY_TXP); also elsewhere on the board
/H3/EPHY_TX-: U1.A3 (EPHY_TXN); also elsewhere on the board
/H3/KEYADC: R62.2, U1.AA5 (KEYADC)
/H3/PWR_CPUFB: TP1.1, U1.T10 (VDD-CPUFB); also elsewhere on the board
/H3/PWR_DRAM: U1.M6 (PL9); also elsewhere on the board
/H3/PWR_IO: U1.R2 (PL5); also elsewhere on the board
/H3/PWR_KEY: R66.2, U1.R1 (PL3)
/H3/PWR_SYSTEM: U1.T2 (PL8); also elsewhere on the board
/H3/PWR_VSET: U1.T4 (PL6); also elsewhere on the board
/H3/RECOVERY: R68.2, U1.N2 (PL4)
/H3/RESET: C130.2, Q5.3 (C), R65.2, U1.V6 (RESET)
/H3/SDIO_CLK: U1.J3 (SDC1_CLK); also elsewhere on the board
/H3/SDIO_CMD: U1.L2 (SDC1_CMD); also elsewhere on the board
/H3/SDIO_D0: U1.H4 (SDC1_D0); also elsewhere on the board
/H3/SDIO_D1: U1.F3 (SDC1_D1); also elsewhere on the board
/H3/SDIO_D2: U1.C2 (SDC1_D2); also elsewhere on the board
/H3/SDIO_D3: U1.C1 (SDC1_D3); also elsewhere on the board
/H3/SD_CLK: U1.D20 (PF2); also elsewhere on the board
/H3/SD_CMD: U1.F18 (PF3); also elsewhere on the board
/H3/SD_D0: U1.A19 (PF1); also elsewhere on the board
/H3/SD_D1: U1.D19 (PF0); also elsewhere on the board
/H3/SD_D2: U1.C20 (PF5); also elsewhere on the board
/H3/SD_D3: U1.E21 (PF4); also elsewhere on the board
/H3/SD_DET: U1.G18 (PF6); also elsewhere on the board
/H3/UBOOT: R67.2, U1.W6 (UBOOT)
/H3/USB_D0+: U1.A5 (USB_D0+); also elsewhere on the board
/H3/USB_D0-: U1.B5 (USB_D0-); also elsewhere on the board
/H3/USB_D1+: U1.B6 (USB_D1+); also elsewhere on the board
/H3/USB_D1-: U1.B7 (USB_D1-); also elsewhere on the board
/H3/VRA1: C33.2, U1.Y4 (VRA1)
/H3/VRA2: C32.1, R4.1, U1.W5 (VRA2)
/H3/VRP: C30.1, C31.2, U1.V4 (VRP)
/H3/WIFI_32K: U1.P3 (X32KFOUT); also elsewhere on the board
/H3/WL_HOST_WAKE: U1.T3 (PL7); also elsewhere on the board
/H3/WL_REG_ON: U1.F13 (PA8); also elsewhere on the board
/H3/X24MI: C127.1, U1.K2 (X24MIN), Y3.2
/H3/X24MO: C128.1, U1.K1 (X24MOUT), Y3.4
/H3/X32KI: C34.1, R6.1, U1.V5 (X32KIN), Y1.2
/H3/X32KO: C39.1, R6.2, U1.U4 (X32KOUT), Y1.1
/H3/eMMC_CLK: U1.A17 (PC5); also elsewhere on the board
/H3/eMMC_CMD: U1.E16 (PC6); also elsewhere on the board
/H3/eMMC_D0: U1.B18 (PC8); also elsewhere on the board
/H3/eMMC_D1: U1.C17 (PC9); also elsewhere on the board
/H3/eMMC_D2: U1.D17 (PC10); also elsewhere on the board
/H3/eMMC_D3: U1.C18 (PC11); also elsewhere on the board
/H3/eMMC_D4: U1.B17 (PC12); also elsewhere on the board
/H3/eMMC_D5: U1.B19 (PC13); also elsewhere on the board
/H3/eMMC_D6: U1.F17 (PC14); also elsewhere on the board
/H3/eMMC_D7: U1.C19 (PC15); also elsewhere on the board
/H3/~BT_CTS: U1.E3 (UART1_CTS); also elsewhere on the board
/H3/~BT_RST: U1.D13 (PA9); also elsewhere on the board
/H3/~BT_RTS: U1.C3 (UART1_RTS); also elsewhere on the board
/H3/~eMMC_RST: U1.H16 (PC16); also elsewhere on the board
GND: C1.1, C2.1, C3.1, C4.1, C7.1, C8.1, C9.2, C10.2, C11.2, C12.1, C13.1, C14.1, C15.2, C16.1, C17.1, C18.1, C19.1, C20.2, C21.1, C22.1, C23.1, C24.1, C25.1, C26.1, C27.1, C34.2, C35.1, C36.1, C37.1, C38.1, C39.2, C127.2, C128.2, C130.1, Q5.2 (E), R1.2, R2.1, R3.2, R5.2, R63.2, U1.A21 (GND), U1.AA1 (GND), U1.G8 (GND), U1.H8 (GND_TV), U1.H12 (GND), U1.H15 (GND), U1.J9 (GND), U1.J13 (GND), U1.J16 (GND), U1.K7 (GND), U1.K8 (GND), U1.K9 (GND), U1.K13 (GND), U1.K14 (GND), U1.K15 (GND), U1.K16 (GND), U1.L8 (GND), U1.L9 (GND), U1.L15 (GND), U1.M5 (GPDI_GND), U1.M7 (GND), U1.M8 (GND), U1.M9 (GND), U1.M10 (GND), U1.M11 (GND), U1.M12 (GND), U1.M13 (GND), U1.M14 (GND), U1.M15 (GND), U1.N7 (GND), U1.N9 (GND), U1.N10 (GND), U1.N11 (GND), U1.N12 (GND), U1.N13 (GND), U1.N14 (GND), U1.N15 (GND), U1.P10 (GND), U1.P11 (GND), U1.P12 (GND), U1.P13 (GND), U1.P14 (GND), U1.P15 (GND), U1.R9 (GND), U1.R10 (GND), U1.R11 (GND), U1.R12 (GND), U1.R13 (GND), U1.R14 (GND), U1.T11 (GND), Y3.1, Y3.3; also elsewhere on the board
unnamed: C129.2, R63.1, R64.1
unnamed: Q5.1 (B), R64.2
unnamed: R2.2, U1.V10 (SZQ)
unnamed: C10.1, U1.G10 (VDD-EFUSE)
unnamed: R1.1, U1.F6 (EPHY_RTX)
unnamed: R3.1, U1.T9 (GND-CPUFB)
unnamed: TP2.1, U1.A1 (JTAG-SEL0)
unnamed: TP3.1, U1.B2 (JTAG-SEL1)
unnamed: R61.2, U1.AA6 (NMI)
VDD_CPUS: C11.1, C25.2, C26.2, U1.J7 (VDD-CPUS), U1.J8 (VDD-CPUS), U1.M4 (RTC_VIO)
VREF: C9.1, U1.T16 (SVREF); also elsewhere on the board

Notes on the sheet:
Accessible via resistor
USB0 is OTG
This isn't a laptop so no power key & KEYADC
FIXME: KEYADC

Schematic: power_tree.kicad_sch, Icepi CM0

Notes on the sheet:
1.2V/2A
3.3V/1A
1.5V/1A
1.3V/3A
H3 Debugging Guide
3.3V/0.5A
DRAM
SY8089A
SY8088
VCC-IO 3.3v AVCC 3.3v VCC-RTC 3.3v VCC3V-PLL 3.3v VCC3V-TV 3.3v VCC-DRAM 1.5v VDD-CPUX 1.3v VDD1V1-EPHY 1.2v VDD1V2-SYS 1.2v
AVCC
USB-C PD 5V/5A (25W)
SY8113
VCC-CPUX
VCC-IO
RTC
SY8088 1A 1.5MHz SY8089A 2A 1MHz SY8113B 3A 0.5MHz
SYSTEM
VCC-WIFI

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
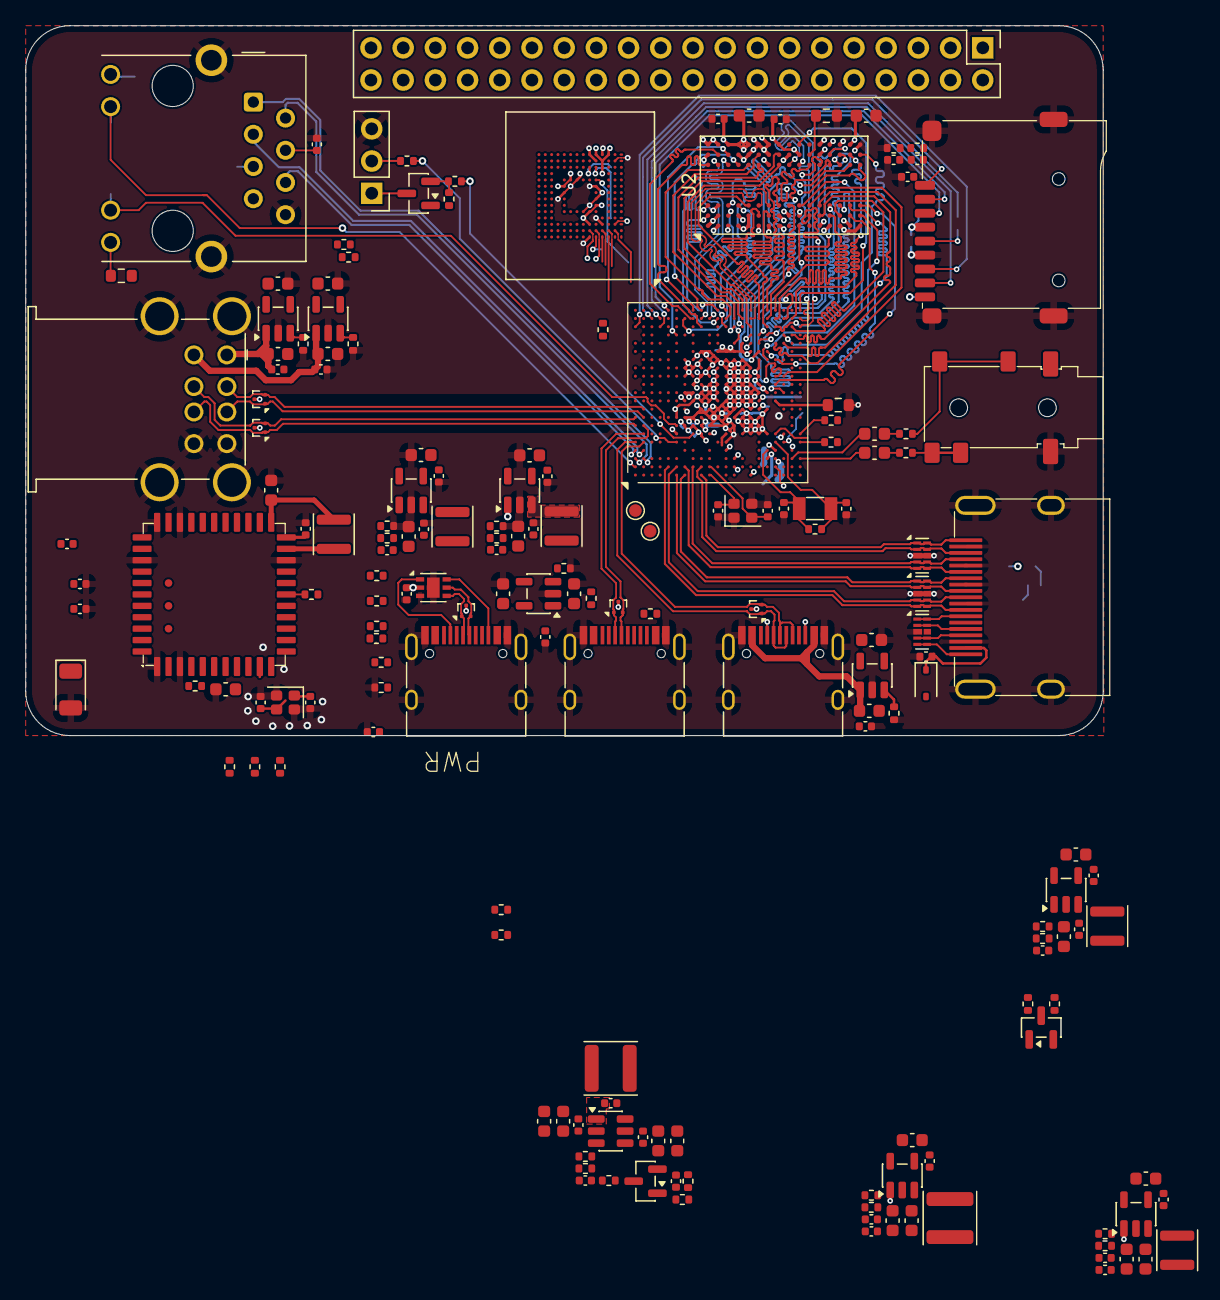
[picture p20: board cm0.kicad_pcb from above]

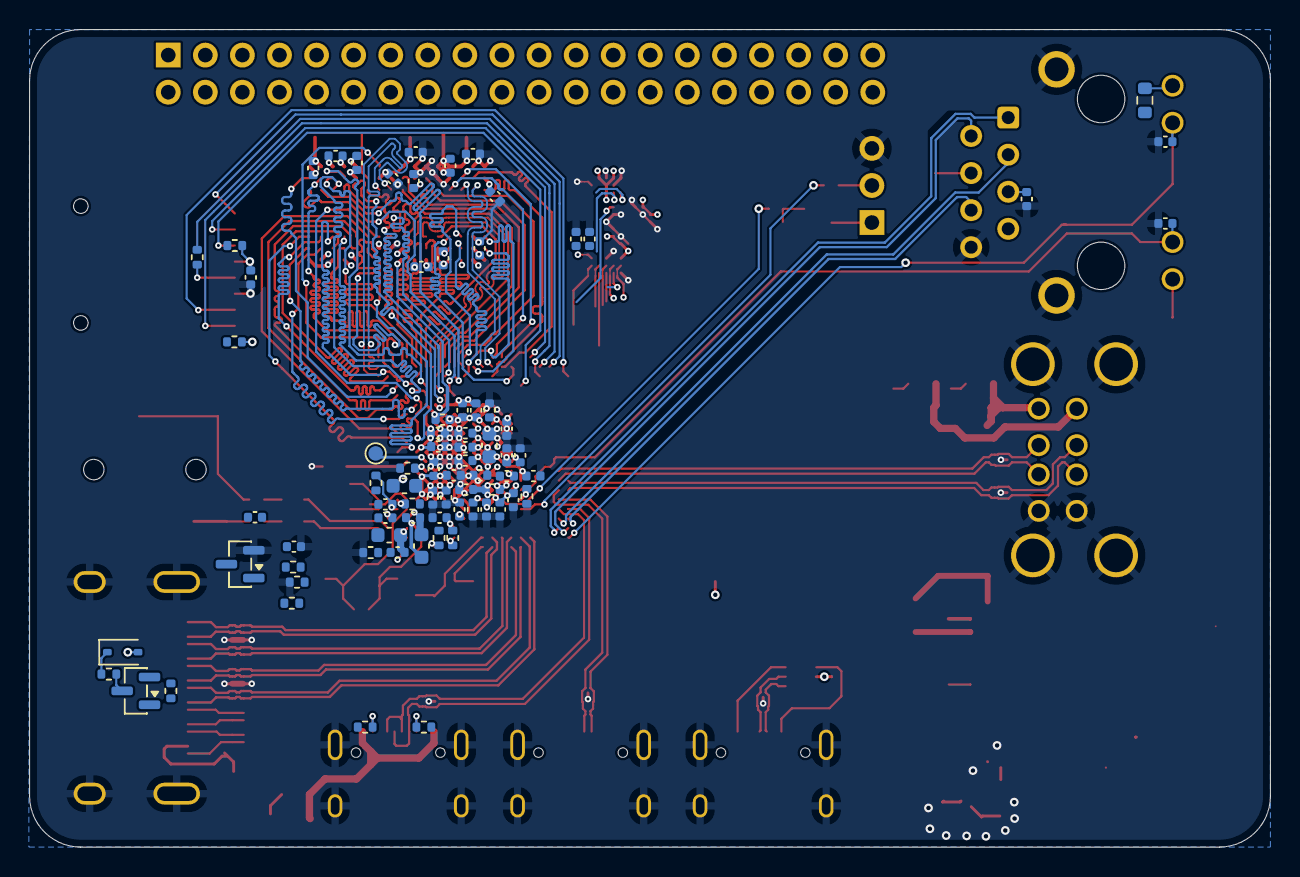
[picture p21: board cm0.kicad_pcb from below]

Board: 4 copper layers, 85.0 x 56.0 mm, 252 parts (77 on the bottom side), 209 nets.

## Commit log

2025-11-04 Decoupled DDR3 and drew RJ45 connector
    [cm0.kicad_pcb, cm0.kicad_sch, cpu.kicad_sch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]
2025-11-08 Initial layout
    [audio.kicad_sch, cm0.kicad_pcb, cm0.kicad_sch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]
2025-11-10 Finished DC DC converters and started decoupling the CPU
    [audio.kicad_sch, cm0.kicad_pcb, cpu.kicad_sch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]
2025-11-11 Decoupling on PCB side almost done
    [audio.kicad_sch, cm0.kicad_pcb, cpu.kicad_sch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]
2025-11-12 Routed DCDC, EPHY and SD
    [cm0.kicad_pcb, cpu.kicad_sch, gpio.kicad_sch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]
2025-11-15 Add Solderpad license
2025-12-19 Update crystal
    [audio.kicad_sch, cm0.kicad_sch, cpu.kicad_sch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]
2025-12-20 Changed crystal and fix USB data lines
    [cpu.kicad_sch, ddr3.kicad_sch, usb.kicad_sch]
2025-12-22 Updated README and improved audio routing
    [audio.kicad_sch, cm0.kicad_sch]
2025-12-22 Add schematic pdf
    [audio.kicad_sch, cm0.kicad_sch, cpu.kicad_sch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]
